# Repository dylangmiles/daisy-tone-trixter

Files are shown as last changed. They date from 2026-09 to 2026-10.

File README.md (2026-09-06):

# Tone Trixter — Daisy Seed3

A guitar pedal that makes a piezo pickup sound like a studio microphone — in real time.

**Build log & demos:** [dylangmiles.github.io/tone-trixter](https://dylangmiles.github.io/tone-trixter/)

Piezo pickups are cheap and reliable but have a characteristic harsh, nasal "quack" that EQ alone
can't fix. Tone Trixter applies an **acoustic body impulse response** to the live piezo signal using
FFT convolution, transforming it to match a condenser microphone placed in front of the same guitar.

**Status: the active development path.** The pedal plays — guitar in, DSP chain, SD-loaded IR,
backing tracks, tuner and OLED menu all running on hardware from a 9 V supply. New work happens
here; the [RP2350 build](https://github.com/dylangmiles/pico-tone-trixter) is the V1 prototype that
proved the idea and is still gigging.

---

## Why the Seed3

The V1 measurements kept arriving at the same conclusion: **the analogue front end sets the noise
floor**, not the DSP. The RP2350 build's ES8388 codec was itself a meaningful part of the noise
budget, which made that conclusion hard to test cleanly.

The Seed3's TAC5242 is 32-bit / 192 kHz with a −120 dB floor. The codec effectively stops being a
factor, and the front-end buffer becomes the *only* thing that matters for noise — which is exactly
the question this project turns on. The 480 MHz Cortex-M7 is a bonus rather than the reason.

---

## Hardware

**Processor:** Electrosmith Daisy Seed3 — STM32H750, Cortex-M7 @ 480 MHz, hardware FPU, 64 MB SDRAM
**Codec:** TI TAC5242 — 32-bit / 192 kHz, −120 dB noise floor, hardware-strapped

```
Guitar piezo → buffer daughter board (JFET follower, or OPA1642 op-amp)
  → Seed3 ADC
    → 2048-tap IR convolution (inline) → input trim → 3-band EQ
      → compressor/limiter → output level
    → backing-track mix (after the chain, deliberately)
  → Seed3 DAC → PA / headphones / interface
```

The piezo buffer lives on a swappable 5-pin daughter board, shared with the V1 build. ⚠ **The Seed3
has no input buffer of its own** and its input is line-level, so the high-impedance buffer stage is
mandatory rather than optional.

Built on cut-down perfboard with the Seed under-mounted, 9 V jack power, SH1106 OLED + rotary
encoder, two footswitches (tuner / DSP bypass), and a bit-banged microSD slot.

---

## Features

- **2048-tap IR convolution**, running inline on the M7 — no second core needed
- **DSP chain:** input trim → 3-band EQ (RBJ biquads) → compressor/limiter → output level
- **Presets** bundling all parameters plus IR selection; switching guitars re-stages the whole chain
- **SD card:** drop `tonetrix/` on a card to override presets (`presets.txt`) and add IRs
  (`ir/*.wav`) without reflashing
- **Backing tracks** streamed from the card, mixed *after* the chain so the bed never goes through
  the guitar's IR, EQ or compressor
- **YIN tuner**, full-screen, footswitch-toggled, muting, fed from the raw input
- **OLED home screen:** preset, IR, CPU load, and in / gain-reduction / out meters with a sticky
  clip indicator
- **Live USB-serial control:** every parameter adjustable while playing (`help` lists commands),
  plus timing, CPU and encoder diagnostics

⚠ **Boot is complete passthrough by design.** The pedal always starts transparent, so anything
measured at boot reflects the front end alone with no DSP on top — which matters while the analogue
path is still being characterised.

---

## Measured performance

Steady state, 48 kHz, 64-sample blocks, chain + 2048-tap IR engaged:

| Figure | Reading |
|---|---|
| Audio CPU, bypass | 1 % |
| Audio CPU, chain + IR | **16 % avg, 45 % peak** |
| Foreground loop | 6.6 ms worst, 8 ms period |
| Backing ring | 98–99 %, 0 underruns |
| Block latency | 1.33 ms |

⚠ **Two budgets, and only one is tight.** Audio has ~84 % spare — the foreground is the constrained
side, where a full OLED flush costs ~28 ms. Any optimisation belongs there, not in the audio path.

---

## Build and flash

Requires the ARM GCC toolchain, `dfu-util`, and [libDaisy](https://github.com/electro-smith/libDaisy)
+ [DaisySP](https://github.com/electro-smith/DaisySP).

```sh
make                                          # or: make LIBDAISY_DIR=/path/to/libDaisy
make program-boot                             # ONCE — installs the Daisy bootloader
make program-dfu                              # thereafter
screen /dev/tty.usbmodem* 115200              # console
```

⚠ **libDaisy must be the `seed3-updates` branch, pinned to a commit.** Seed3 support is not on
`main` — a stock libDaisy configures the wrong codec, and an unmerged branch can be force-pushed
underneath you.

⚠ **`APP_TYPE = BOOT_SRAM`.** The STM32H750 has only 128 KB of internal flash and this app does not
fit; it runs from 480 KB of internal SRAM via the Daisy bootloader, which is why `make program-boot`
is a required one-time step.

---

## Notes worth knowing before you read the code

Several things here deliberately do *not* use the obvious library call. Each has a measured reason,
documented at the point of use:

- **Our own SH1106 driver.** libDaisy's OLED transport sends one I²C transaction *per byte* — about
  77 ms per frame. Ours writes a page per transaction and sends only pages that changed.
- **Our own quadrature decode.** libDaisy's `Encoder::Increment()` needs one exact sample pattern
  that a detented PEC11R rarely produces; it works only within a narrow band of turn speeds.
- **Bit-banged SD over SPI.** The Daisy's SDMMC `CMD` pin is wired to ground on this layout, and the
  breakout's pin order matches no hardware SPI instance.
- **`-u _printf_float` in the Makefile.** libDaisy links `--specs=nano.specs`, and newlib-nano omits
  floating-point conversion from `printf` — every `%f` silently prints nothing without it.

`CLAUDE.md` carries the full engineering detail, including the hardware gotchas that cost bench time.

---

## Relationship to the RP2350 build

The two pedals share the analogue front end, the DSP chain design, the IR capture method, and **one
physical SD card** — the card layout lives once, in the
[Pico repo](https://github.com/dylangmiles/pico-tone-trixter), and both firmwares read it.

Driver sources that could reasonably be shared are kept byte-identical between the builds behind
small platform shims, so a protocol or layout fix on either platform applies to both.

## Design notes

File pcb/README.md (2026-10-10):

# Tone Trixter PCB — rev A

KiCad 10 project. **The schematic is GENERATED**: edit `tools/gen_schematic.py`, run it, never hand-edit
`tone_trixter.kicad_sch` (the next run overwrites it). Design intent and every value's reason are in
`private/docs/daisy_pcb_brief_2026-09-16.md`; pin numbers come from `../board.h`.

```
tools/gen_schematic.py          # the source of truth for the schematic
tools/kisch.py, tools/kisym.py  # tiny writer + KiCad-library symbol extractor
tone_trixter.kicad_sch          # generated
tone_trixter.kicad_pro          # project (created once)
TT.kicad_sym, sym-lib-table     # the Daisy Seed3 symbol, built from the pinout CSV
tone_trixter_schematic.pdf      # review print
```

Check: `kicad-cli sch erc tone_trixter.kicad_sch` (only "symbol differs from library" notices expected —
the op-amp and SD symbols are flattened copies) and `kicad-cli sch export netlist`. `gen_schematic.py`
also runs a wire-through-pin check and prints `CHECK:` lines if any wire crosses a pin it should not.

## Layout (started 2026-10-09)

The enclosure mock-up revised the brief's board envelope. **Current geometry** (see
`tools/gen_mockup_svg.py` + `tools/gen_side_elevation_svg.py`, rendered in `mockup/`):

- 1590XX **landscape** (internal top-face plane 138 × 114, **2.33 mm walls**, internal cavity **33 mm**
  tall, Ø7 corner bosses). All measured off the box 2026-10-10.
- **Full-width board ~132 × 57 mm**, hugging the **back wall**, rear corners notched **10 × 10** for the
  bosses (Ø7 post → 3 mm play). Mounted high under the top face (**gap 8.24 mm**, set by the OLED glass
  flush + encoder body clearing); **Seed hangs ~16.5 below**; OLED + encoder reach up (screen centred on
  the board, toward the rear); footswitches panel-mounted up front at 90 mm centres.
- **TRS + DC jacks bottom-mounted** (barrel 12.4 below the board → axis **~33 % up the wall, lower
  third**, z ≈ 10.8), legs up through the PCB, isolated plastic bushings. **USB = Seed's own port** on a
  flexible extender. **Two high-Z inputs drilled in v1** — IN A (AIN1) + IN B (AIN2), both K3599 TRS;
  the XLR mic reserve is dropped (a v2 board).
- ✅ All Z-stack heights (OLED/encoder/Seed/jack/cavity) **measured** 2026-10-10; see the side-elevation.

**The outline is GENERATED** — `tools/gen_board.py` (run with KiCad's bundled python; has `pcbnew`):

```
/Applications/KiCad/KiCad.app/Contents/Frameworks/Python.framework/Versions/Current/bin/python3 \
    tools/gen_board.py          # writes tone_trixter.kicad_pcb: Edge.Cuts outline + M3 holes only
```

Then in KiCad: open `tone_trixter.kicad_pcb`, **Tools → Update PCB from Schematic (F8)** to pull in
the 102 footprints (the schematic has them all assigned), place per the mock-up, route, DRC, 3D-check
against the box height, Gerbers. One plane (bottom pour), star at power entry; no copper within 1 mm
of the edge; mounting holes become plane-bonded once the enclosure bond is finalised.

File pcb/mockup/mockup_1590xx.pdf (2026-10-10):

## 1590XX mock-up (landscape) -- PRINT AT 100%, verify the 100 mm ruler

Box: ext ~145x121x39 (catalog), wall 2.33, top-face plane 138x114, cavity 33 tall, O7 corner bosses.
Full-width notched board; jacks board-mounted. IN A + IN B = two high-Z TRS inputs (both drilled v1).

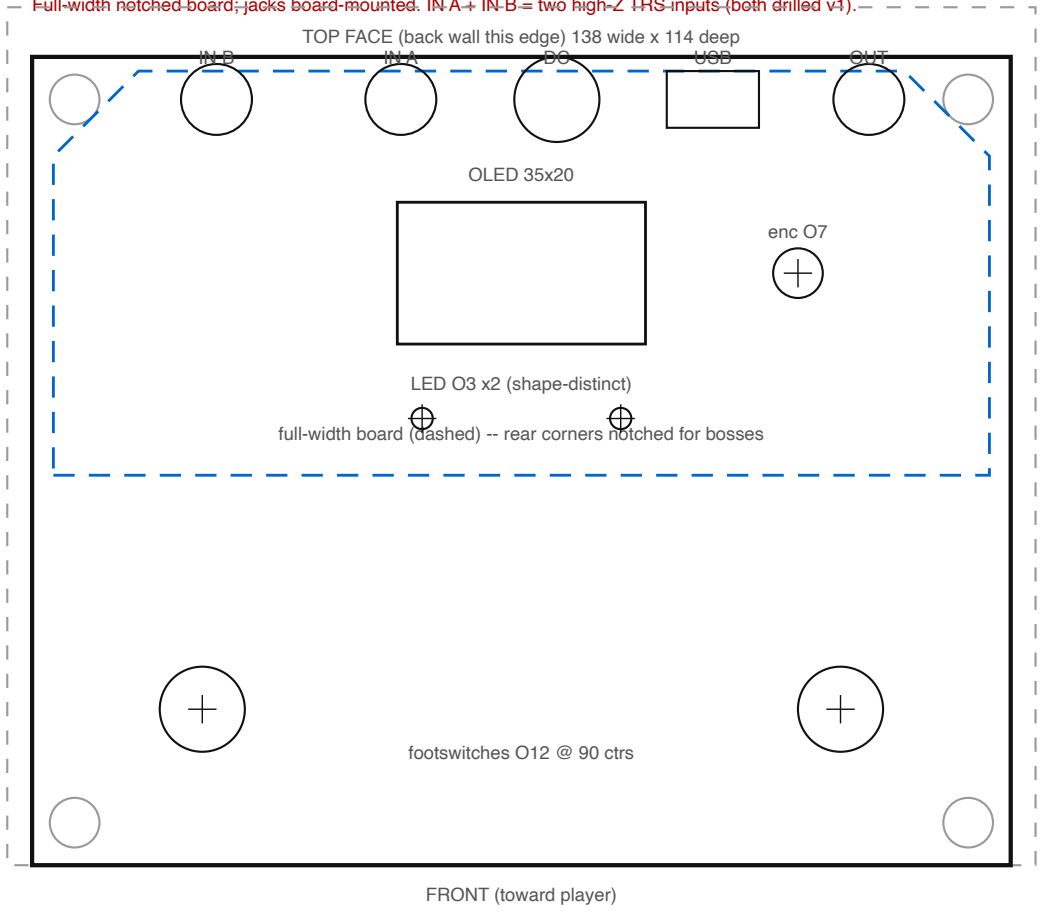
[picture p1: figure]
FRONT (toward player); footswitches O12 @ 90 ctrs; LED O3 x2 (shape-distinct); OLED 35x20; enc O7; USB; OUT

TOP FACE (back wall this edge) 138 wide x 114 deep

full-width board (dashed) -- rear corners notched for bosses

REAR WALL drilling strip (138 wide x 33 tall, base at BOTTOM) -- same X as above; hole at its axis height

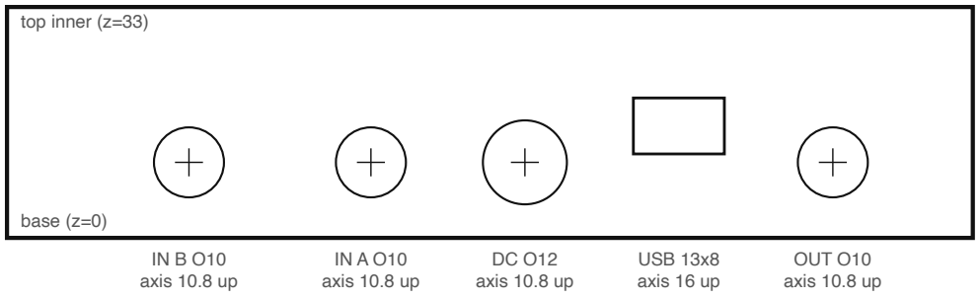
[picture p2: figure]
base (z=0); top inner (z=33); IN B O10 axis 10.8 up; IN A O10 axis 10.8 up; DC O12 axis 10.8 up; USB 13x8 axis 16 up; OUT O10 axis 10.8 up

this bar MUST measure 100.0 mm -- if not, fix the print scale

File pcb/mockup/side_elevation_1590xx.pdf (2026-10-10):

## 1590XX SIDE ELEVATION (height study, projected) -- PRINT AT 100%

ALL heights MEASURED off the prototype + box 2026-10-10 (recalibrated caliper). Front=left, back wall=right.
Cavity 33 mm (35.30 box - 2.3 top), walls 2.33 mm. Gap 8.24 (OLED glass flush, encoder clears). Jack axis 12.4 below the board.

top face

base plate

FRONT (toward player) --- BACK WALL (jacks)

Seed3 + sockets ~16.5
(hangs below the PCB)
| OLED glass (flush w/ top inner)
PCB | | standoff 8.24

encoder shaft (+16.61 over top)

jack z=10.77 (bottom-mt)

0 base

7 Seed btm

11 jack axis

25 board/jack

33 top inner

Jacks BOTTOM-MOUNTED (barrel below the board) -> axis z=9.8 = ~33% up the 33 mm wall (lower third) -- barrel drop 12.4 + the 8.2 gap the gap the controls force. Check the plug + base-plate battery box do not crowd down there on the casting.
Seed hangs to ~6.7 mm over the base (16.5 stack). TRS/DC bottom-mount, legs up; USB = Seed's own port.

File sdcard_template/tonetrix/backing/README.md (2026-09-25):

# Backing tracks

Drum beds for playing along. Select with the OLED `BK:` menu row, or over UART:

    bk                 list (* = playing)
    bk 0 | bk blues92  play by index or name
    bk off             stop
    bk level 0.8       level, independent of out.level
    bk stat            ring fill, underruns, worst service time

Loops are **pure data** — drop a new WAV in this folder and `bk scan` picks it up.
No reflash. Any rate, 8/16/24/32-bit or float, mono or stereo; it is resampled to the
engine rate on the fly. These are 48 kHz mono 16-bit, peak −6 dBFS to leave headroom
for the guitar summed on top.

## Beat 1 is marked with a bell

Every bar's **1** carries a short inharmonic bell (~2.1 kHz, ~55 ms). It is
deliberately not a kit voice: a few dB of accent is easy to lose once a guitar is on
top, so the downbeat differs in *timbre*, not level. Inharmonic rather than a pure
tone, so it reads as percussion instead of a note that fights whatever key you are in.

Turn it down or off when you no longer need it — see *Regenerating* below.

## The loops

⚠ **Song suggestions are starting points, not matches.** These are generic grooves in
the right style — never reproductions. The tempos were chosen from where each style
usually sits, **not measured against any recording**, so expect to want a nudge.

| File | bpm | Feel | Try it with |
|---|---|---|---|
| `delta72` |  72 | Sparse Delta shuffle, as `delta81`, slower | **"Come Back Baby" — Lightnin' Hopkins** *(requested)* |
| `stomp71` |  71 | **Foot-stomp + handclap**: kick on all four, claps on 2 and 4, nothing else | **"Am I Wrong" — Keb' Mo'** *(requested 2026-09-18)* |
| `blues71` |  71 | Same country blues shuffle as `blues92`, slower and heavier | slow shuffle |
| `delta81` |  81 | **Sparse Delta shuffle**: kick 1 & 3, rim 2 & 4, whisper of hat | **"Walking Blues" — Muddy Waters**, **"Sweet Home Chicago"** *(requested)* |
| `ballad62`  |  62 | **Slow 4/4 ballad, as sparse as it gets**: kick on 1, rim on 3, brushed 2 & 4 barely there | **"Desperado" — Eagles** *(requested)* |
| `folksh92`  |  92 | Slow brushed **12/8 shuffle** (in four), swirl on the "and" | **"Angel from Montgomery" — Prine / Raitt** *(requested)* |
| `folksh96`  |  96 | Gentle 12/8 lilt, brushed | **"Wonderful Tonight" — Eric Clapton** *(requested)* |
| `ssoul78` |  78 | **Slow soul pocket**: kick 1 + pickup into 3, cross-stick 2 & 4, light swung hat | **"Ain't No Sunshine" — Bill Withers** *(requested)* |
| `waltz100`  | 100 | **3/4 waltz** (in three), bass on 1, brushed 2 & 3, light hat | **"Scarborough Fair" — Simon & Garfunkel** *(requested)* |
| `rise76` |  76 | **True 6/8**, felt in TWO — bass on 1 & 4, light hat over the six eighths | **"House of the Rising Sun" — The Animals** *(requested)* |
| `folksh76`  |  76 | Slow brushed shuffle, **12/8 (counted in four)**, swirl on the shuffle "and" | slow 12/8 blues/ballads |
| `blues81` |  81 | Same country blues shuffle as `blues92`, a little slower | slow Delta blues, slide |
| `folkd92` |  92 | **Driving acoustic folk-rock**: kick on every beat, snare 2 & 4, 8th hat | **"Can't Find My Way Home" — Blind Faith** *(requested)* |
| `folkd140`  | 140 | Same driving folk bed, up-tempo country strum | **"Wagon Wheel" — Old Crow / Darius Rucker** *(requested; 150 eased to 140)* |
| `blues92` |  92 | Country blues shuffle, 12/8, ride-style hat, ghost notes | acoustic country blues, slide |
| `delta92` |  92 | Sparse Delta shuffle, as `delta81` | **"Cross Road Blues"** acoustic *(requested)* |
| `delta100`  | 100 | Sparse Delta shuffle, as `delta81` | (spare) |
| `delta101`  | 101 | Sparse Delta shuffle, as `delta81` | **"Cross Road Blues"** *(requested)* |
| `delta110`  | 110 | Sparse Delta shuffle, as `delta81`, brisker | **"Cross Road Blues"** faster *(requested)* |
| `blues100`  | 100 | Same country blues shuffle as `blues92`, a touch brisker | **"I Can't Be Satisfied" — Muddy Waters** *(requested)* |
| `folk104` | 104 | Light two-step with brushes, cross-stick | country folk, fingerstyle |
| `rock120` | 120 | Straight 8ths, backbeat, open-hat lift into the turnaround | general rock |
| `folkr128`  | 128 | Gentle country-folk-rock, soft brushed backbeat, sparse kick | **"Old Man" — Neil Young**, **"Father and Son" — Cat Stevens** *(requested)* |
| `rkbly138`  | 138 | Rockabilly, handclaps on the backbeat, more bounce | slower take on the below |
| `soul140` | 140 | Soul-pop with a little pocket | slower take on the below |
| `soull150`  | 150 | **Soul-pop, simplified**: kick 1 & 3, snare 2 & 4, straight hat, no ghosts, no fill | **"Brown Eyed Girl" — Van Morrison** *(requested; the full kit was busy under strummed acoustic)* |
| `soul150` | 150 | Bright uptempo soul-pop, full kit, driving 8ths | the busier take on the above |
| `rkbly145`  | 145 | Rockabilly bounce, handclaps doubling the backbeat | **"Crazy Little Thing Called Love" — Queen** *(requested; 156 was too quick)* |
| `rkbly156`  | 156 | Rockabilly bounce, handclaps doubling the backbeat | brisker take on the above |

All are **4 bars**, seamless, and start exactly on beat 1.

⚠ `blues71` / `blues81` / `blues92` / `blues100` are the **same groove at four tempos** — identical pattern,
identical swing. Rendered from one style, so a change to the feel applies to all three:

    python3 tools/gen_backing_loops.py country_blues --bpm 71     # from daisy/

## Regenerating

Everything here is synthesised by `daisy/tools/gen_backing_loops.py` (moved from `pico/tools/`
on 2026-09-18 — the Pico copy is frozen with that build) —
no samples, nothing licensed. Grooves are data (step/velocity lists in `STYLES`), so
changing a pattern is an edit, not new code.

    python3 tools/gen_backing_loops.py                     # all styles, defaults
    python3 tools/gen_backing_loops.py rock --bpm 132      # retune one
    python3 tools/gen_backing_loops.py soul_pop --bpm 140 --swing 0.06
    python3 tools/gen_backing_loops.py rock --ping 0       # no beat-1 bell

Knobs: `--bpm`, `--swing` (0 = straight, ~0.33 = full triplet), `--accent` (beat-1
level), `--ping` (beat-1 bell level, 0 = off). The render line prints all four, so a
re-render says what it did.

⚠ **The tempo is part of the filename.** Re-rendering at a new tempo writes a *new*
file rather than replacing the old one — delete the stale one or you will have both
in the picker.

## Loading the card

    cp .../sdcard_template/tonetrix/backing/*.wav /Volumes/<CARD>/tonetrix/backing/
    dot_clean -m /Volumes/<CARD>/tonetrix

`dot_clean` strips the `._name.wav` sidecars macOS writes on FAT volumes. The firmware
ignores them, but they clutter the card.

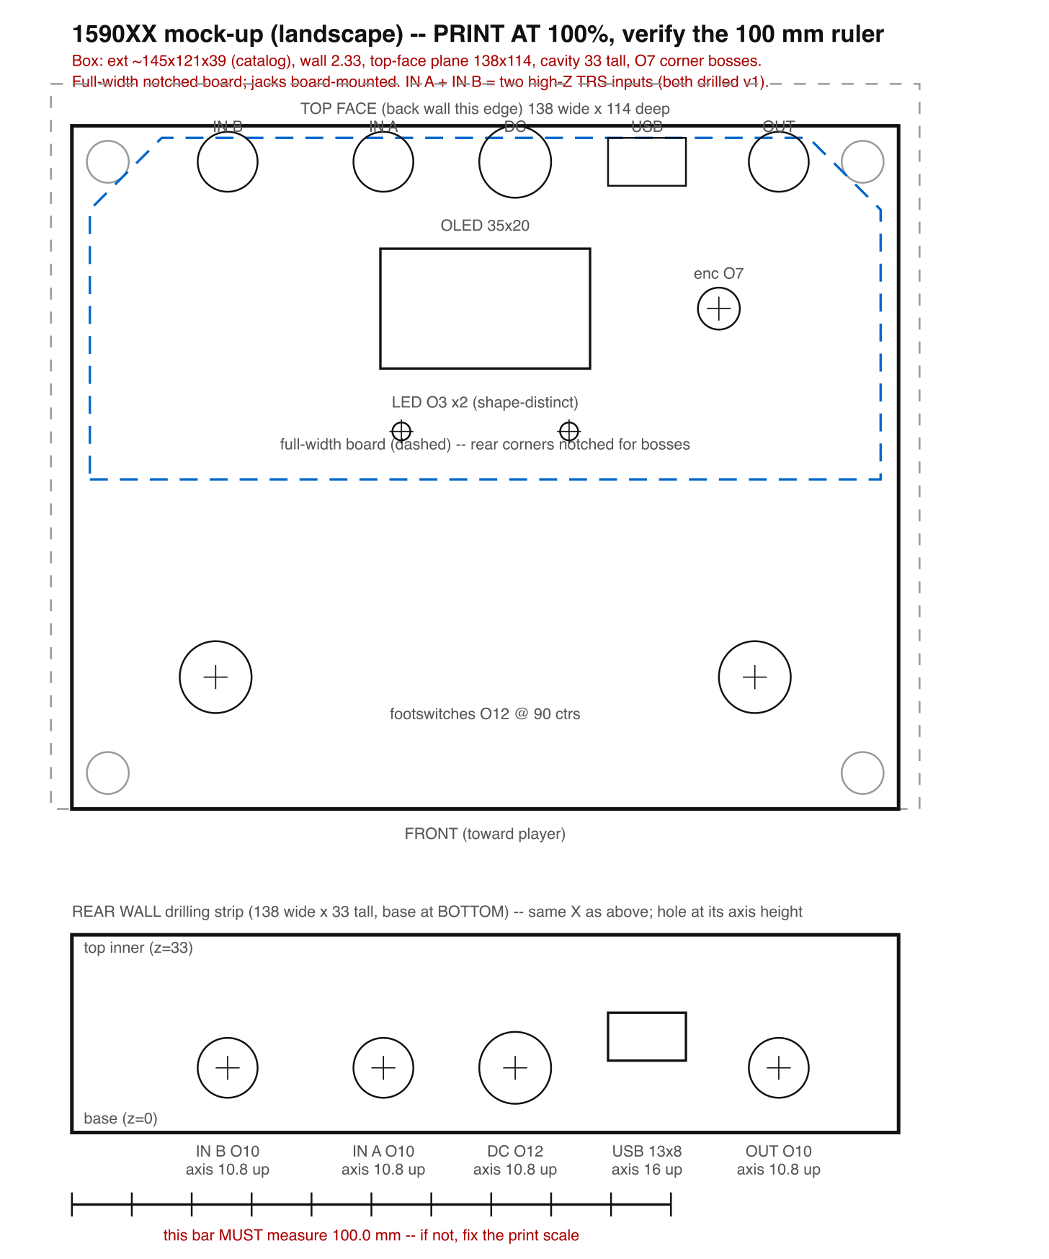
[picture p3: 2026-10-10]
pcb/mockup/mockup_preview.png

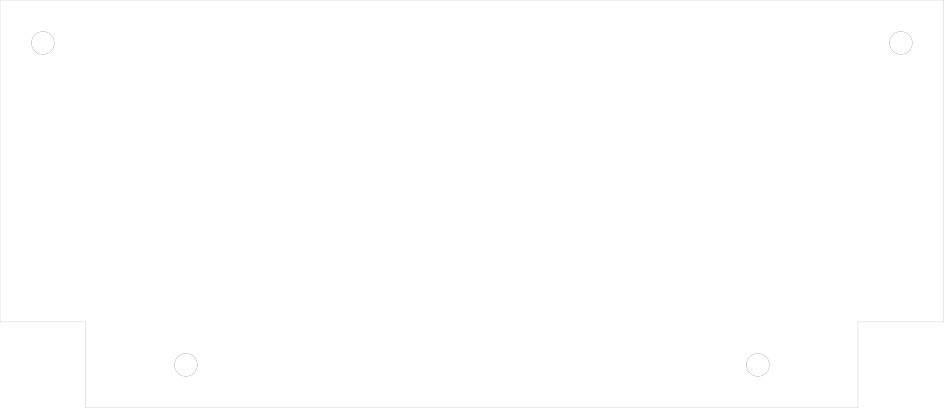
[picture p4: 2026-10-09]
pcb/mockup/board_outline_preview.png

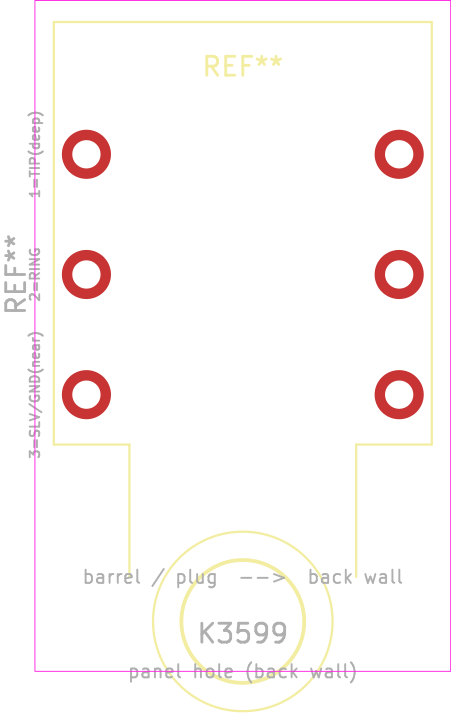
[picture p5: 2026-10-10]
pcb/mockup/k3599_footprint.png

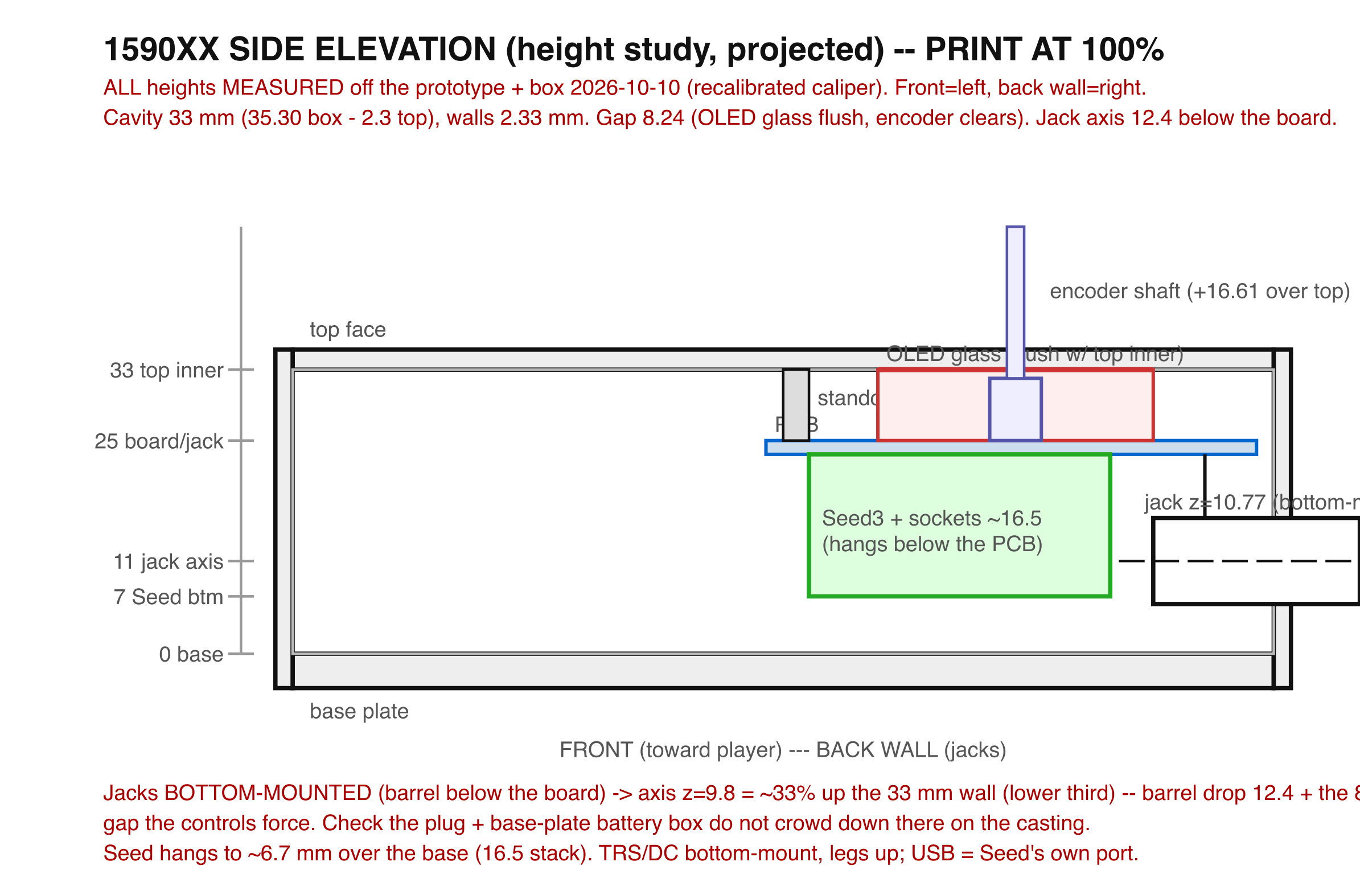
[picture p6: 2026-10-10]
pcb/mockup/side_elevation_preview.png

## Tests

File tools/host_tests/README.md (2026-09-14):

# Host tests

Engine logic that is cheap to prove on the Mac and expensive to debug underfoot.

```
cd tools/host_tests
c++ -std=c++14 -O1 -I../.. -I. looper_test.cpp ../../audio/looper.cpp -o looper_test && ./looper_test
```

`dev/sdram.h` stubs `DSY_SDRAM_BSS` so `looper.cpp` compiles unchanged. Covers: first pass → play,
overdub auto-commit after one loop, undo stack, an overdub cut short (extent tracking), stop/play
from the top, tempo lock (bpm + bars), bar snap (bpm only), the 60 s cap, and the free-loop bpm guess.

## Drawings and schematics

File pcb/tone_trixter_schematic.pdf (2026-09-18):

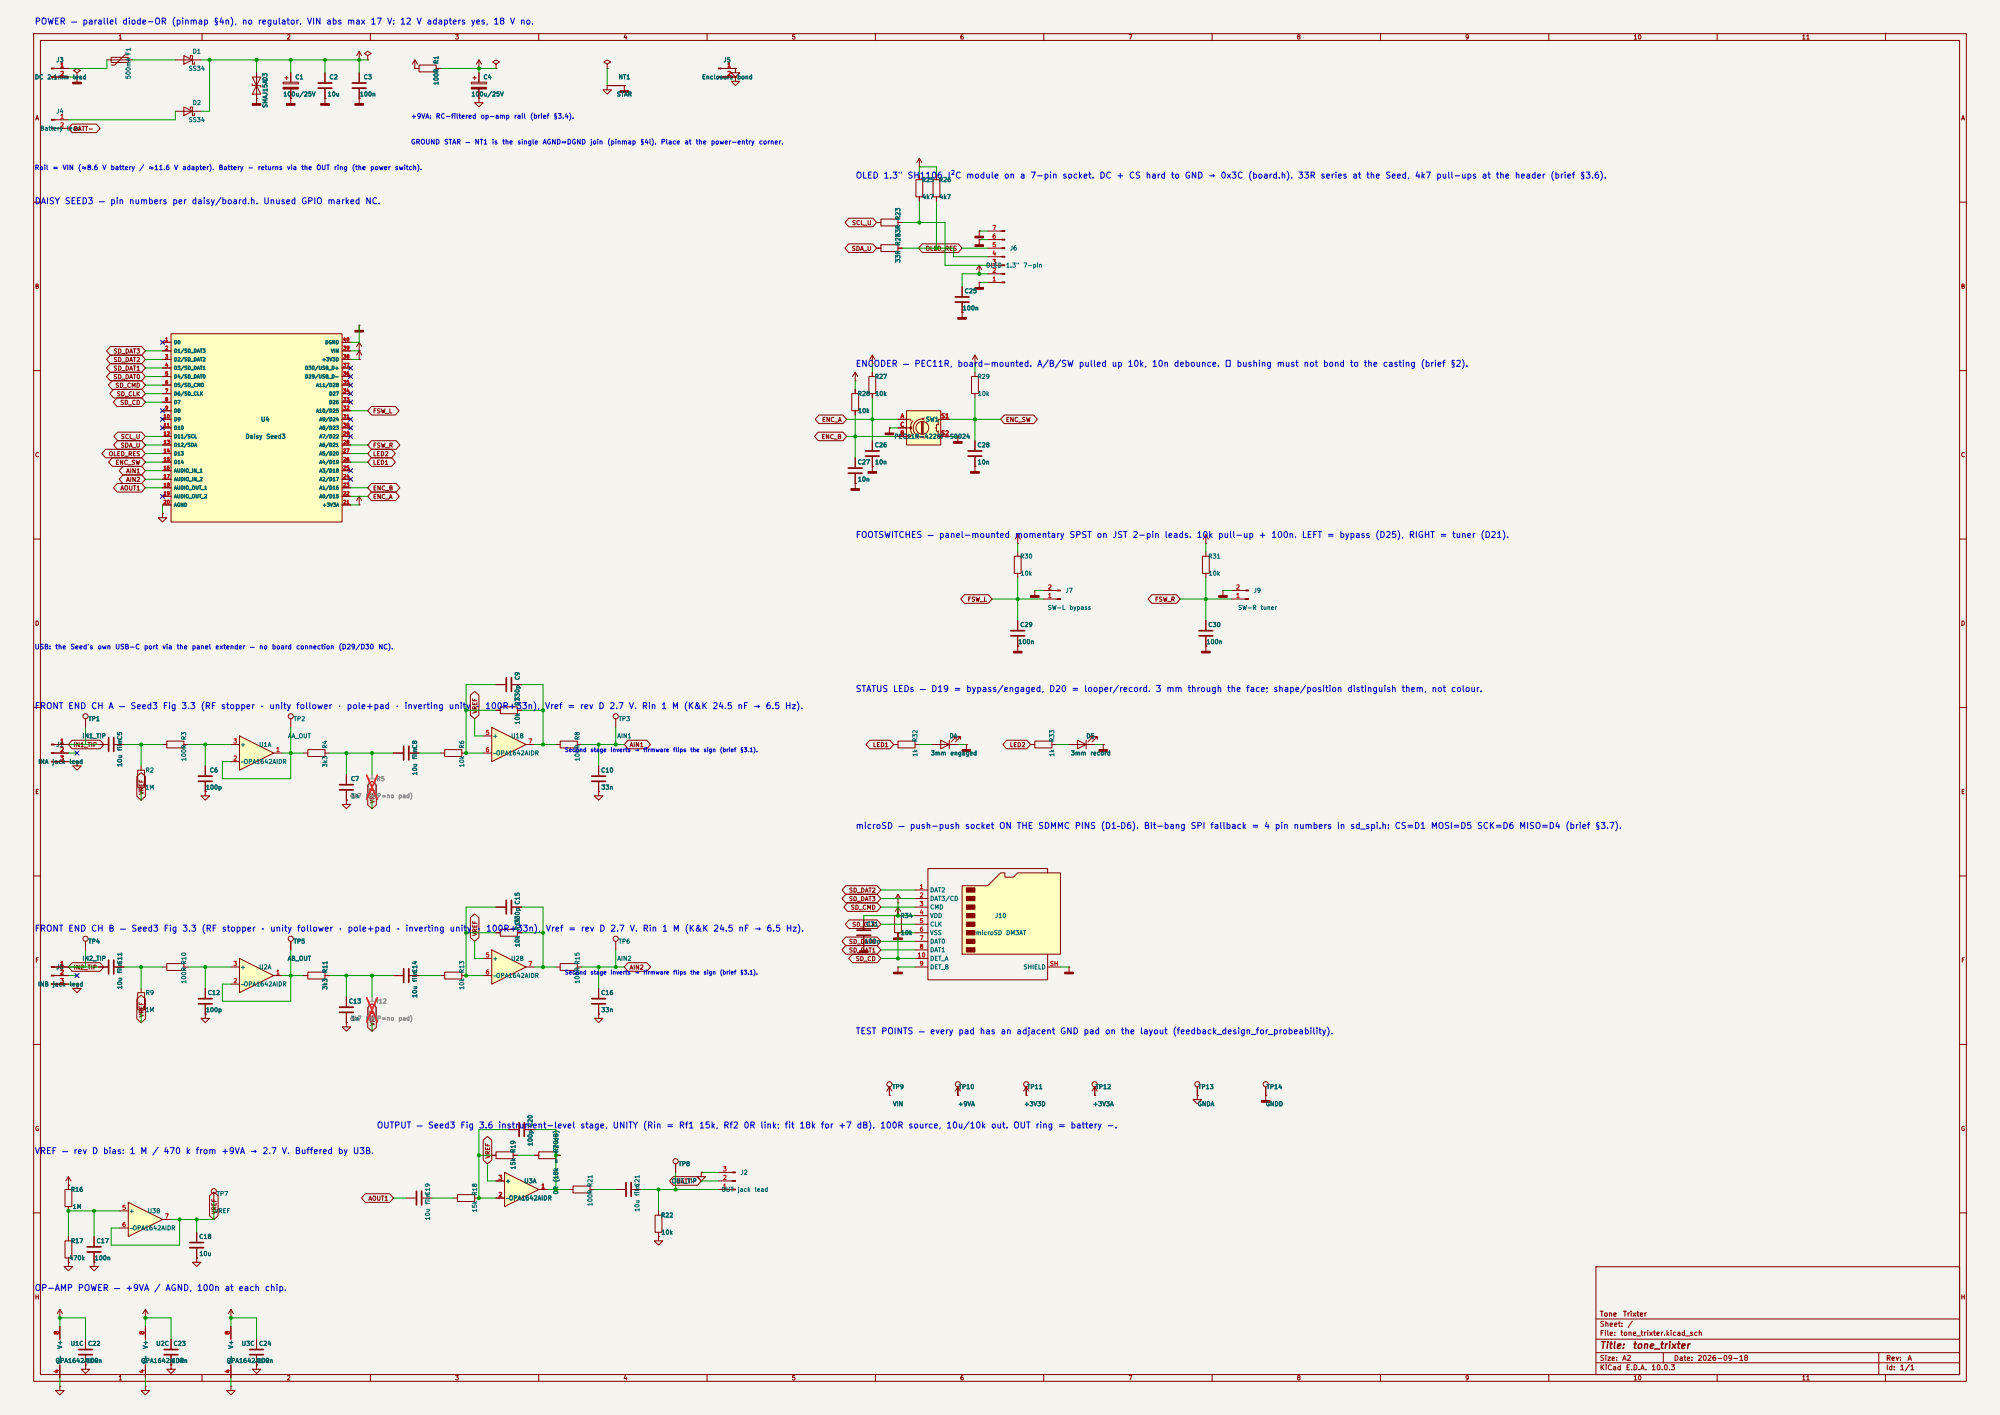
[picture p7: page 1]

POWER — parallel diode-OR (pinmap §4n), no regulator. VIN abs max 17 V: 12 V adapters yes, 18 V no.
100u/25V D3 SMAJ15A U4 Daisy Seed3

+9VA: RC-filtered op-amp rail (brief §3.4). GROUND STAR — NT1 is the single AGND↔DGND join (pinmap §4l). Place at the power-entry corner.

DAISY SEED3 — pin numbers per daisy/board.h. Unused GPIO marked NC. Rail = VIN (≈8.6 V battery / ≈11.6 V adapter). Battery − returns via the OUT ring (the power switch).

OLED 1.3" SH1106 I²C module on a 7-pin socket. DC + CS hard to GND → 0x3C (board.h). 33R series at the Seed, 4k7 pull-ups at the header (brief §3.6).

ENCODER — PEC11R, board-mounted. A/B/SW pulled up 10k, 10n debounce. ⚠ bushing must not bond to the casting (brief §2).

FOOTSWITCHES — panel-mounted momentary SPST on JST 2-pin leads. 10k pull-up + 100n. LEFT = bypass (D25), RIGHT = tuner (D21).

STATUS LEDs — D19 = bypass/engaged, D20 = looper/record. 3 mm through the face; shape/position distinguish them, not colour.

microSD — push-push socket ON THE SDMMC PINS (D1–D6). Bit-bang SPI fallback = 4 pin numbers in sd_spi.h: CS=D1 MOSI=D5 SCK=D6 MISO=D4 (brief §3.7).

TEST POINTS — every pad has an adjacent GND pad on the layout (feedback_design_for_probeability). C11 10u film

OUTPUT — Seed3 Fig 3.6 instrument-level stage, UNITY (Rin = Rf1 15k, Rf2 0R link; fit 18k for +7 dB). 100R source, 10u/10k out. OUT ring = battery −.

VREF — rev D bias: 1 M / 470 k from +9VA → 2.7 V. Buffered by U3B.

OP-AMP POWER — +9VA / AGND, 100n at each chip.

Size: A2 | Rev: A
KiCad E.D.A. 10.0.3 | Id: 1/1

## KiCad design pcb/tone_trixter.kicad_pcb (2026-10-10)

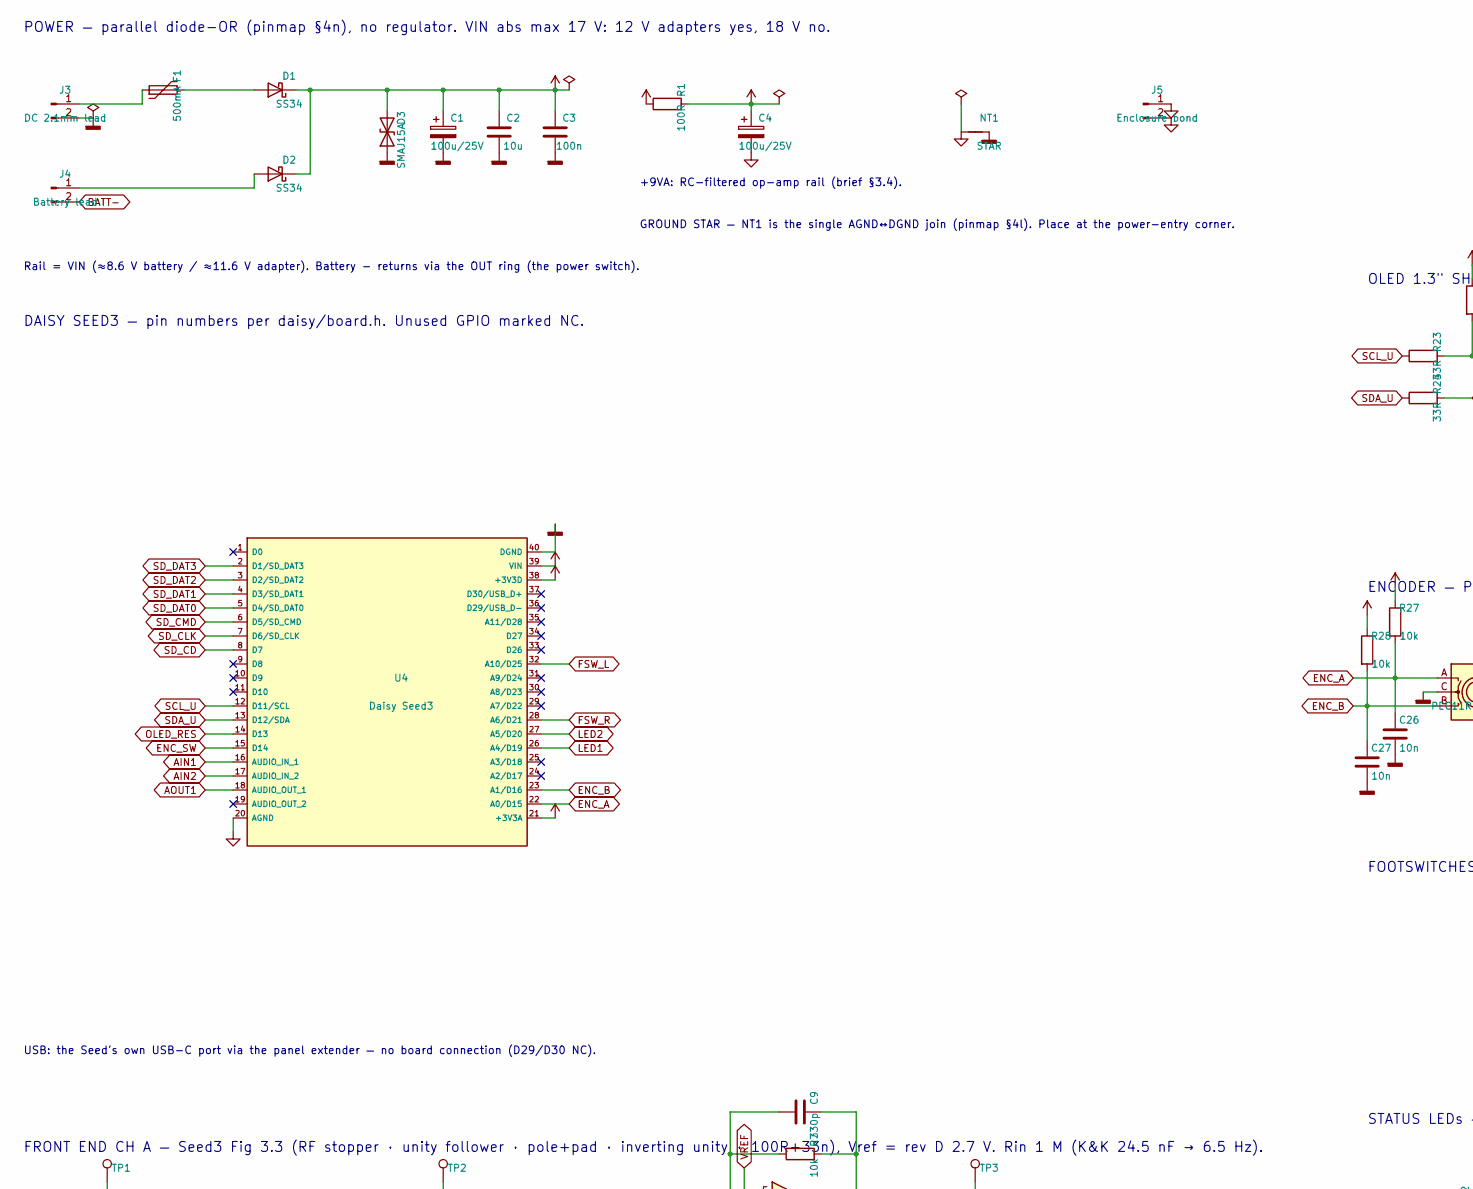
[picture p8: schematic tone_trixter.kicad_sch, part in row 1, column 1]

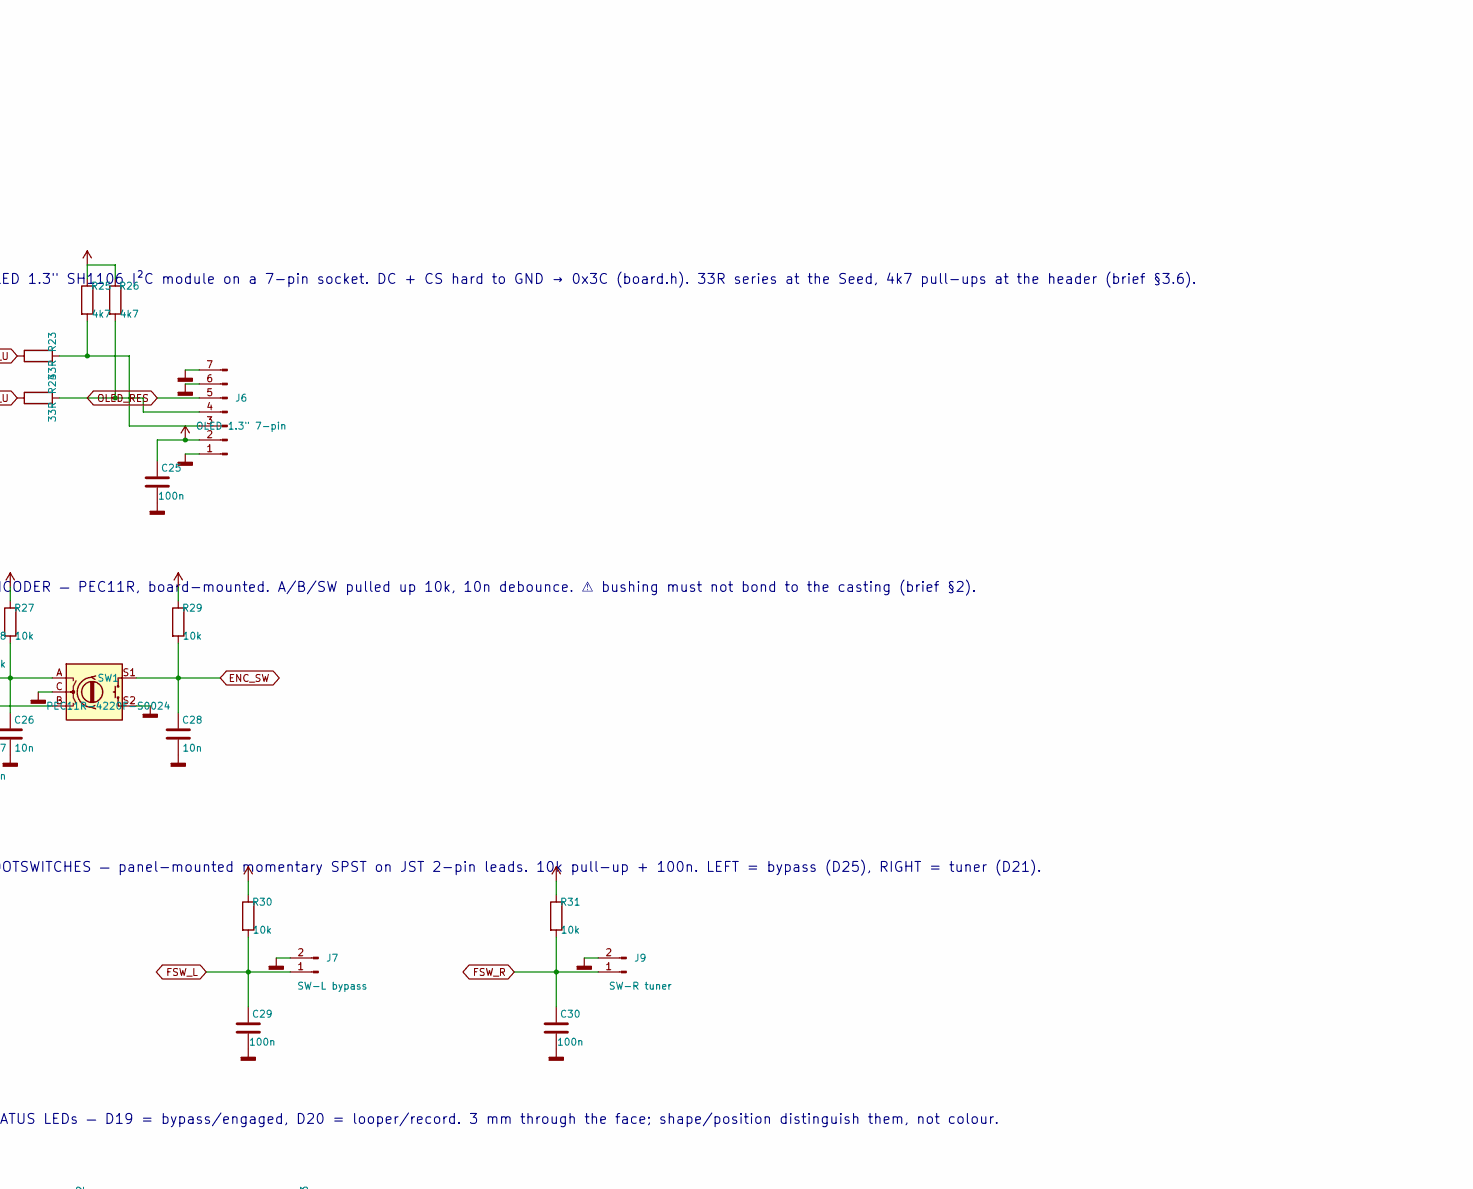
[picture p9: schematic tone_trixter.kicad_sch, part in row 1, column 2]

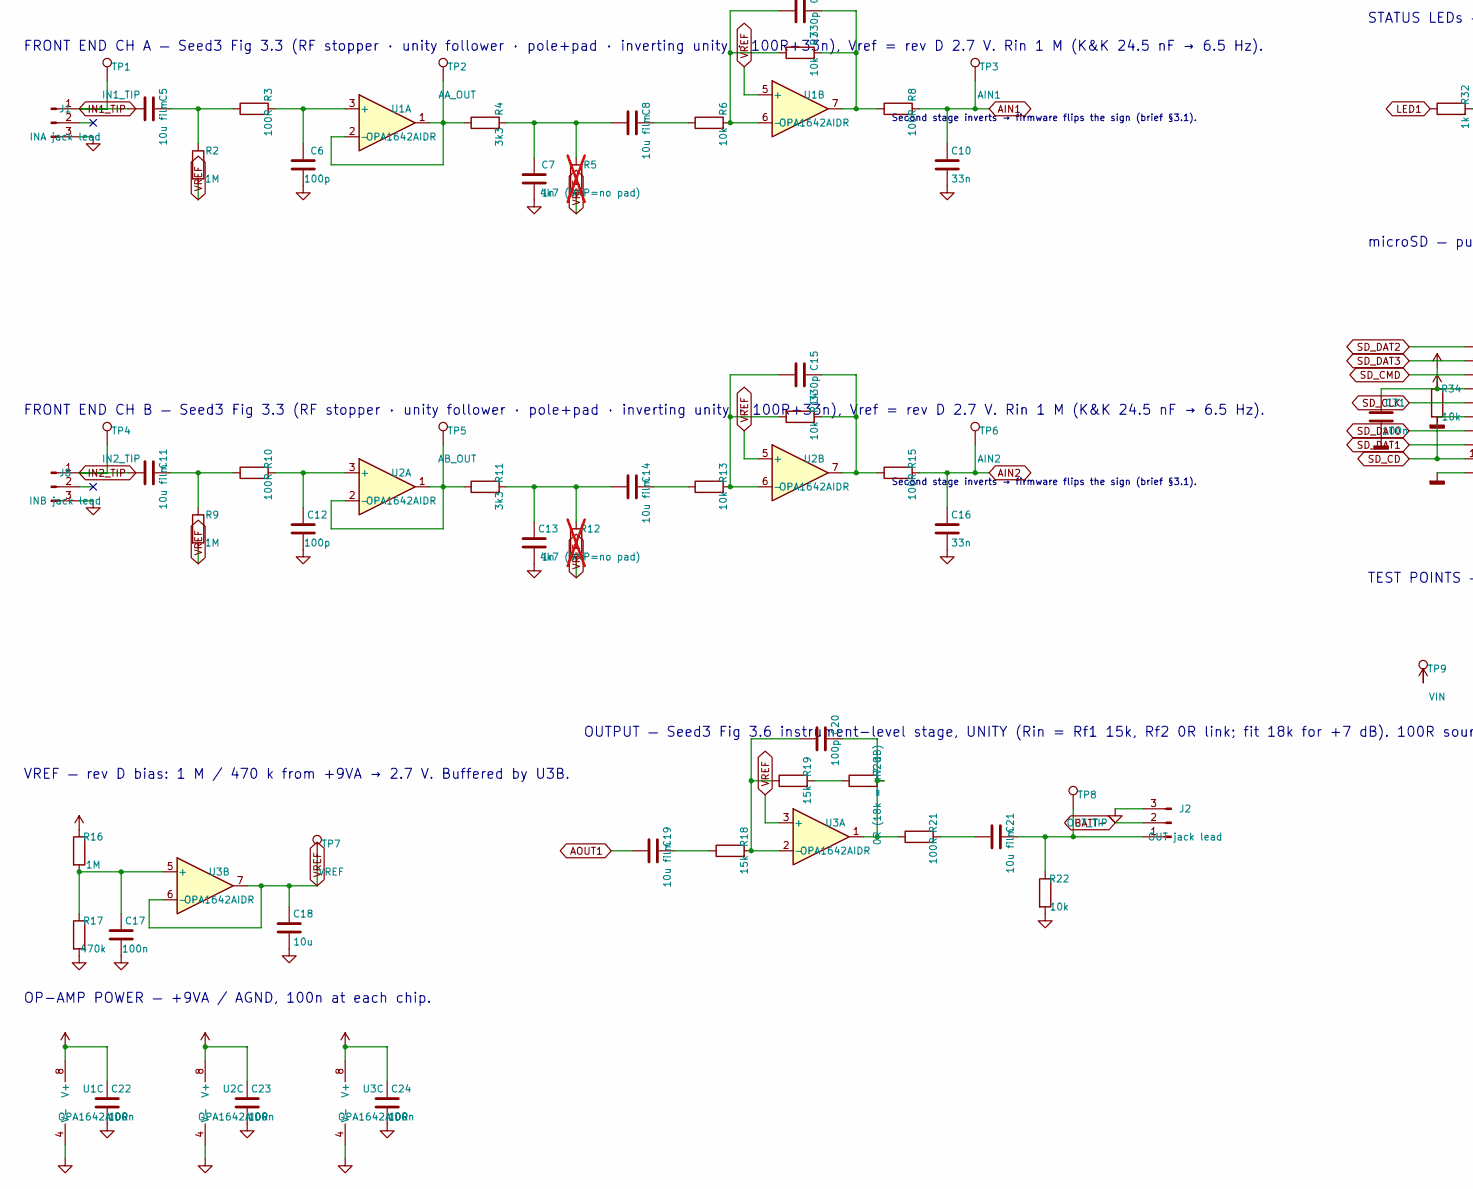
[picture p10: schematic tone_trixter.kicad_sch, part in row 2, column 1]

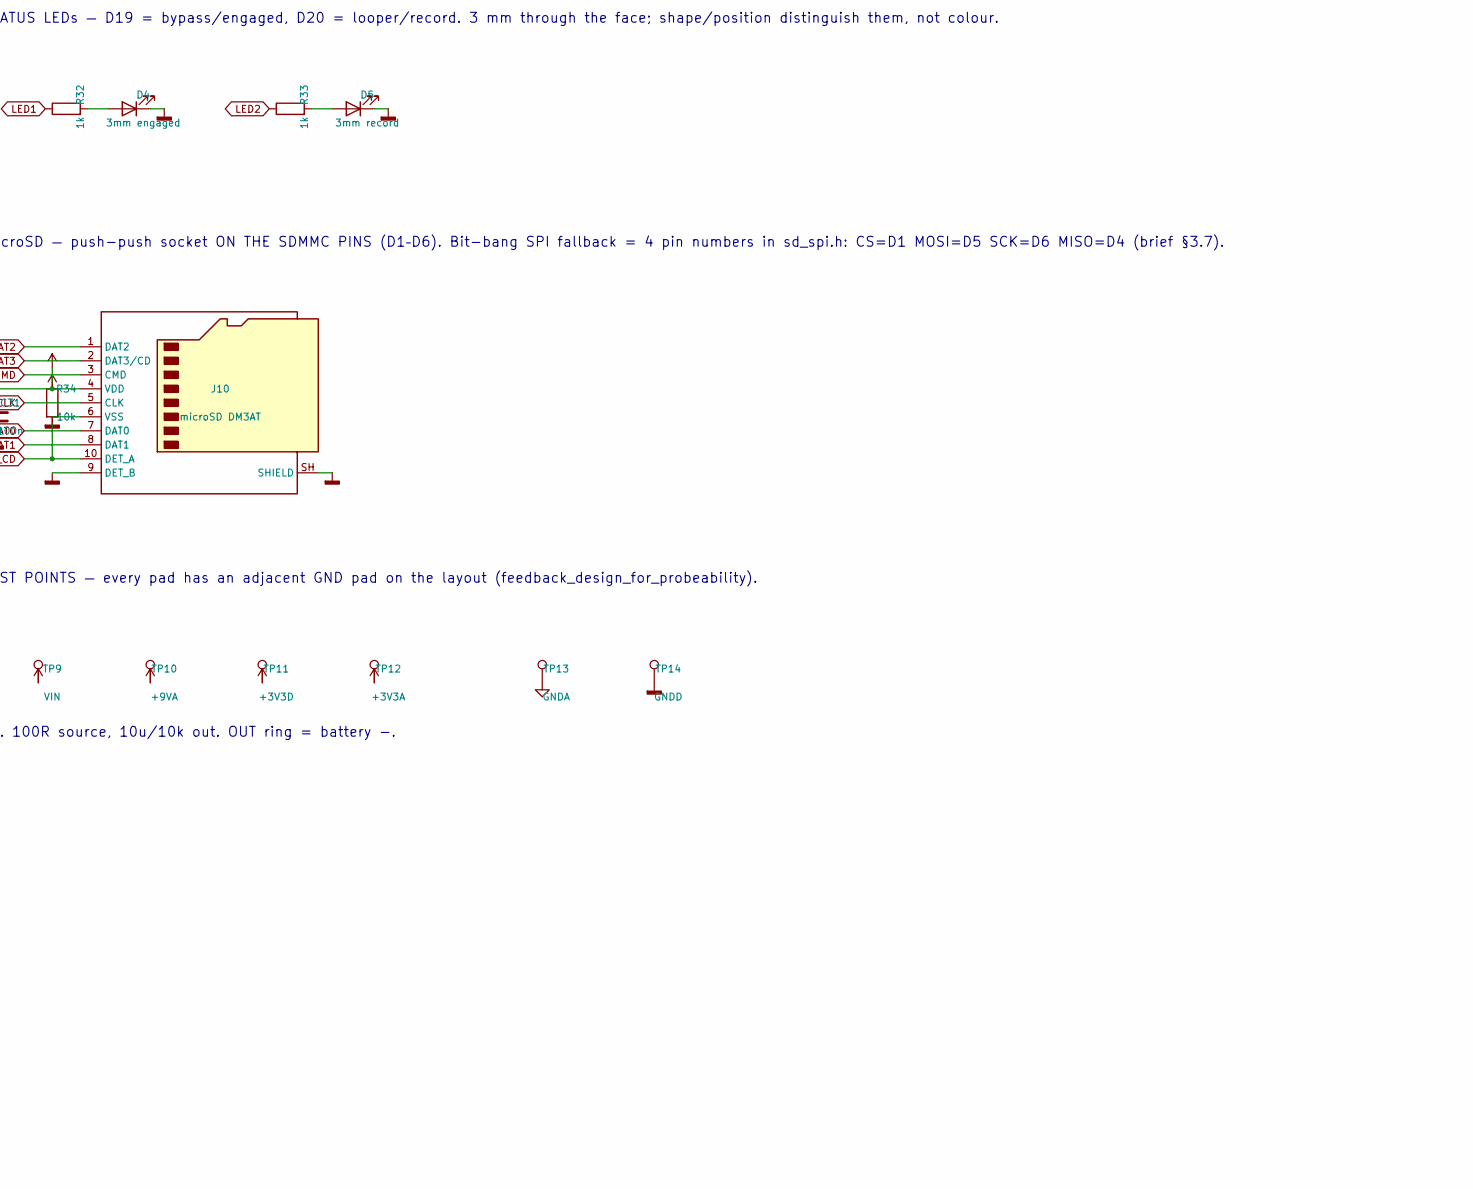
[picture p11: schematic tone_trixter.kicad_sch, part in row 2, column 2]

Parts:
C1, C4: 100u/25V; CP_Radial_D6.3mm_P2.50mm
C2, C18: 10u; C_0805_2012Metric
C3, C17, C22, C23, C24, C25, C29, C30, C31: 100n; C_0805_2012Metric
C5, C8, C11, C14, C19, C21: 10u film; C_Rect_L7.2mm_W7.2mm_P5.00mm_FKS2_FKP2_MKS2_MKP2
C6, C12, C20: 100p; C_0805_2012Metric
C7, C13: 1n; C_0805_2012Metric
C9, C15: 330p; C_0805_2012Metric
C10, C16: 33n; C_0805_2012Metric
C26, C27, C28: 10n; C_0805_2012Metric
D1, D2: SS34; D_SMA; LCSC C8678
D3: SMAJ15A; D_SMA; LCSC C129213
D4: 3mm engaged; LED_D3.0mm
D5: 3mm record; LED_D3.0mm
F1: 500mA; Fuse_1812_4532Metric; LCSC C883116
J1: INA jack lead; K3599_TRS_6leg
J2: OUT jack lead; K3599_TRS_6leg
J3: DC 2.1mm lead; JST_XH_B2B-XH-A_1x02_P2.50mm_Vertical
J4: Battery lead; JST_XH_B2B-XH-A_1x02_P2.50mm_Vertical
J5: Enclosure bond; JST_XH_B2B-XH-A_1x02_P2.50mm_Vertical
J6: OLED 1.3" 7-pin; PinSocket_1x07_P2.54mm_Vertical
J7: SW-L bypass; JST_XH_B2B-XH-A_1x02_P2.50mm_Vertical
J8: INB jack lead; JST_XH_B3B-XH-A_1x03_P2.50mm_Vertical
J9: SW-R tuner; JST_XH_B2B-XH-A_1x02_P2.50mm_Vertical
J10: microSD DM3AT; microSD_HC_Hirose_DM3AT-SF-PEJM5; LCSC C114218
NT1: STAR; NetTie-2_SMD_Pad0.5mm
R1, R3, R8, R10, R15, R21: 100R; R_0805_2012Metric
R2, R9, R16: 1M; R_0805_2012Metric
R4, R11: 3k3; R_0805_2012Metric
R5, R12: 4k7 (DNP=no pad); R_0805_2012Metric; not fitted
R6, R7, R13, R14, R22, R27, R28, R29, R30, R31, R34: 10k; R_0805_2012Metric
R17: 470k; R_0805_2012Metric
R18, R19: 15k; R_0805_2012Metric
R20: 0R (18k = +7 dB); R_0805_2012Metric
R23, R24: 33R; R_0805_2012Metric
R25, R26: 4k7; R_0805_2012Metric
R32, R33: 1k; R_0805_2012Metric
SW1: PEC11R-4220F-S0024; RotaryEncoder_Alps_EC11E-Switch_Vertical_H20mm_CircularMoun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
TP1: IN1_TIP; TestPoint_Pad_D1.5mm
TP2: AA_OUT; TestPoint_Pad_D1.5mm
TP3: AIN1; TestPoint_Pad_D1.5mm
TP4: IN2_TIP; TestPoint_Pad_D1.5mm
TP5: AB_OUT; TestPoint_Pad_D1.5mm
TP6: AIN2; TestPoint_Pad_D1.5mm
TP7: VREF; TestPoint_Pad_D1.5mm
TP8: OUT_TIP; TestPoint_Pad_D1.5mm
TP9: VIN; TestPoint_Pad_D1.5mm
TP10: +9VA; TestPoint_Pad_D1.5mm
TP11: +3V3D; TestPoint_Pad_D1.5mm
TP12: +3V3A; TestPoint_Pad_D1.5mm
TP13: GNDA; TestPoint_Pad_D1.5mm
TP14: GNDD; TestPoint_Pad_D1.5mm
U1, U2, U3: OPA1642AIDR; SOIC-8_3.9x4.9mm_P1.27mm; LCSC C126004
U4: Daisy Seed3; Electrosmith_Daisy_Seed

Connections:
+3V3A: TP12.1 (1_1), U4.21 (+3V3A)
+3V3D: C25.1, C31.1, J6.2, J10.4 (VDD), R25.1, R26.1, R27.1, R28.1, R29.1, R30.1, R31.1, R34.1, TP11.1 (1_1), U4.38 (+3V3D)
+9VA: C4.1, C22.1, C23.1, C24.1, R1.2, R16.1, TP10.1 (1_1), U1.8 (V+), U2.8 (V+), U3.8 (V+)
AIN1: C10.1, R8.2, TP3.1 (1_1), U4.16 (AUDIO_IN_1)
AIN2: C16.1, R15.2, TP6.1 (1_1), U4.17 (AUDIO_IN_2)
AOUT1: C19.1, U4.18 (AUDIO_OUT_1)
BATT-: J2.2, J4.2
ENC_A: C26.1, R27.2, SW1.A, U4.22 (A0/D15)
ENC_B: C27.1, R28.2, SW1.B, U4.23 (A1/D16)
ENC_SW: C28.1, R29.2, SW1.S1, U4.15 (D14)
FSW_L: C29.1, J7.1, R30.2, U4.32 (A10/D25)
FSW_R: C30.1, J9.1, R31.2, U4.28 (A6/D21)
GNDA: C4.2, C6.2, C7.2, C10.2, C12.2, C13.2, C16.2, C17.2, C18.2, C22.2, C23.2, C24.2, J1.3, J2.3, J5.1, J5.2, J8.3, NT1.1, R17.2, R22.2, TP13.1 (1_1), U1.4 (V-), U2.4 (V-), U3.4 (V-), U4.20 (AGND)
GNDD: C1.2, C2.2, C3.2, C25.2, C26.2, C27.2, C28.2, C29.2, C30.2, C31.2, D3.1 (A1), D4.1 (K), D5.1 (K), J3.2, J6.1, J6.6, J6.7, J7.2, J9.2, J10.6 (VSS), J10.9 (DET_B), J10.SH (SHIELD), NT1.2, SW1.C, SW1.S2, TP14.1 (1_1), U4.40 (DGND)
IN1_TIP: C5.1, J1.1, TP1.1
IN2_TIP: C11.1, J8.1, TP4.1
LED1: R32.1, U4.26 (A4/D19)
LED2: R33.1, U4.27 (A5/D20)
unnamed: C5.2, R2.1, R3.1
unnamed: C7.1, C8.1, R4.2, R5.1
unnamed: C8.2, R6.1
unnamed: C9.2, R7.2, R8.1, U1.7
unnamed: C11.2, R9.1, R10.1
unnamed: C13.1, C14.1, R11.2, R12.1
unnamed: C14.2, R13.1
unnamed: C15.2, R14.2, R15.1, U2.7
unnamed: C19.2, R18.1
unnamed: C20.2, R20.2, R21.1, U3.1
unnamed: C21.1, R21.2
unnamed: D1.2 (A), F1.2
unnamed: D2.2 (A), J4.1
unnamed: D4.2 (A), R32.2
unnamed: D5.2 (A), R33.2
unnamed: C21.2, J2.1, R22.1, TP8.1 (1_1)
unnamed: F1.1, J3.1
unnamed: J6.3, R23.2, R25.2
unnamed: J6.4, R24.2, R26.2
unnamed: R19.2, R20.1
unnamed: C6.1, R3.2, U1.3 (+)
unnamed: R4.1, TP2.1 (1_1), U1.1, U1.2 (-)
unnamed: C9.1, R6.2, R7.1, U1.6 (-)
unnamed: C12.1, R10.2, U2.3 (+)
unnamed: R11.1, TP5.1 (1_1), U2.1, U2.2 (-)
unnamed: C15.1, R13.2, R14.1, U2.6 (-)
unnamed: C20.1, R18.2, R19.1, U3.2 (-)
unnamed: C17.1, R16.2, R17.1, U3.5 (+)
OLED_RES: J6.5, U4.14 (D13)
SCL_U: R23.1, U4.12 (D11/SCL)
SDA_U: R24.1, U4.13 (D12/SDA)
SD_CD: J10.10 (DET_A), R34.2, U4.8 (D7)
SD_CLK: J10.5 (CLK), U4.7 (D6/SD_CLK)
SD_CMD: J10.3 (CMD), U4.6 (D5/SD_CMD)
SD_DAT0: J10.7 (DAT0), U4.5 (D4/SD_DAT0)
SD_DAT1: J10.8 (DAT1), U4.4 (D3/SD_DAT1)
SD_DAT2: J10.1 (DAT2), U4.3 (D2/SD_DAT2)
SD_DAT3: J10.2 (DAT3/CD), U4.2 (D1/SD_DAT3)
VIN: C1.1, C2.1, C3.1, D1.1 (K), D2.1 (K), D3.2 (A2), R1.1, TP9.1 (1_1), U4.39 (VIN)
VREF: C18.1, R2.2, R5.2, R9.2, R12.2, TP7.1 (1_1), U1.5 (+), U2.5 (+), U3.3 (+), U3.6 (-), U3.7

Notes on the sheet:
POWER — parallel diode-OR (pinmap §4n), no regulator. VIN abs max 17 V: 12 V adapters yes, 18 V no.
Rail = VIN (≈8.6 V battery / ≈11.6 V adapter). Battery − returns via the OUT ring (the power switch).
+9VA: RC-filtered op-amp rail (brief §3.4).
GROUND STAR — NT1 is the single AGND↔DGND join (pinmap §4l). Place at the power-entry corner.
DAISY SEED3 — pin numbers per daisy/board.h. Unused GPIO marked NC.
USB: the Seed's own USB-C port via the panel extender — no board connection (D29/D30 NC).
FRONT END CH A — Seed3 Fig 3.3 (RF stopper · unity follower · pole+pad · inverting unity · 100R+33n), Vref = rev D 2.7 V. Rin 1 M (K&K 24.5 nF → 6.5 Hz).
Second stage inverts → firmware flips the sign (brief §3.1).
FRONT END CH B — Seed3 Fig 3.3 (RF stopper · unity follower · pole+pad · inverting unity · 100R+33n), Vref = rev D 2.7 V. Rin 1 M (K&K 24.5 nF → 6.5 Hz).
VREF — rev D bias: 1 M / 470 k from +9VA → 2.7 V. Buffered by U3B.
OUTPUT — Seed3 Fig 3.6 instrument-level stage, UNITY (Rin = Rf1 15k, Rf2 0R link; fit 18k for +7 dB). 100R source, 10u/10k out. OUT ring = battery −.
OP-AMP POWER — +9VA / AGND, 100n at each chip.
OLED 1.3" SH1106 I²C module on a 7-pin socket. DC + CS hard to GND → 0x3C (board.h). 33R series at the Seed, 4k7 pull-ups at the header (brief §3.6).
ENCODER — PEC11R, board-mounted. A/B/SW pulled up 10k, 10n debounce. ⚠ bushing must not bond to the casting (brief §2).
FOOTSWITCHES — panel-mounted momentary SPST on JST 2-pin leads. 10k pull-up + 100n. LEFT = bypass (D25), RIGHT = tuner (D21).
STATUS LEDs — D19 = bypass/engaged, D20 = looper/record. 3 mm through the face; shape/position distinguish them, not colour.
microSD — push-push socket ON THE SDMMC PINS (D1–D6). Bit-bang SPI fallback = 4 pin numbers in sd_spi.h: CS=D1 MOSI=D5 SCK=D6 MISO=D4 (brief §3.7).
TEST POINTS — every pad has an adjacent GND pad on the layout (feedback_design_for_probeability).

Board: 2 copper layers, 101 parts (9 on the bottom side), 58 nets, no tracks yet.

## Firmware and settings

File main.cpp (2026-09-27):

// Tone Trixter — Daisy Seed3 bring-up diagnostics.
//
// Purpose: prove the board is alive and correctly wired BEFORE any audio or DSP code exists.
// Every check here answers one question and reports pass/fail on its own, so a failure points at
// a specific joint rather than "it doesn't work".
//
// This follows the project's hard-won bench rule: separate the variables. On the Pico build,
// three separate faults (a compressor left on, an uncompensated probe, a debug probe radiating
// into a high-Z input) each produced a believable-but-wrong answer because more than one thing
// was in play at once. Diagnostics exist to make that impossible.
//
// Flash:  make program-dfu   (hold BOOT, tap RESET, then run)
// Watch:  screen /dev/tty.usbmodem* 115200   — or any serial terminal at 115200

#include "daisy_seed.h"
#include "board.h"

// ⚠ NO extern "C" wrapper: dsp_chain.cpp compiles as C++ here, so both sides must agree on
// linkage. The header is C-style but the translation unit is C++.
#include "audio/dsp_chain.h"
#include "audio/biquad.h"
#include "audio/tt_store.h"
#include "audio/wav_load.h"
#include "audio/tuner.h"
#include "audio/menu.h"
#include "audio/app_hooks.h"
#include "audio/oled_shim.h"
#include "audio/backing.h"
#include "audio/usb_msc.h"
#include "audio/looper.h"
extern "C" {
#include "ff.h"
#include "ff_gen_drv.h"
extern const Diskio_drvTypeDef tt_sd_driver;
}
#include "TwoStageFFTConvolver.h"

#include <cstdio>
#include <cmath>
#include <cstring>
#include <strings.h>   // strcasecmp
#include <cstdlib>

// ---------------------------------------------------------------------------------------------
// printf → USB console. dsp_chain.cpp (shared with the Pico) reports through printf; on the Pico
// that is the UART, here newlib's default _write is a stub that drops everything -- so `dump`,
// `eq.hi_gain 2` etc. changed the chain and printed nothing (found 2026-09-18). Route stdout to
// the same CDC logger PrintLine() uses, a line at a time so the terminal gets CR LF.
// ⚠ Foreground only: the logger is not interrupt-safe, and neither is anything that printf()s.
extern "C" int _write(int fd, const char* buf, int len)
{
    static char line[160];
    static int  n = 0;
    (void)fd;
    for(int i = 0; i < len; i++)
    {
        const char c = buf[i];
        if(c == '\n' || n == (int)sizeof(line) - 1)
        {
            line[n] = 0;
            daisy::Logger<daisy::LOGGER_INTERNAL>::PrintLine("%s", line);
            n = 0;
            if(c != '\n') line[n++] = c;
        }
        else if(c != '\r')
            line[n++] = c;
    }
    return len;
}

using namespace daisy;

static DaisySeed hw;

// ---------------------------------------------------------------------------------------------
// OLED readout.
//
// ⚠ THIS EXISTS SO THE BOARD CAN BE DIAGNOSED WITHOUT USB. Audio work must run from the 9 V jack:
// on USB the Daisy back-feeds VIN to ~4.9 V, which puts the op-amp daughter's Vref (1.57 V) ABOVE
// its common-mode ceiling (1.41 V) -- the exact out-of-spec condition that measured 8.9 % THD on
// the 5 V build. Every audio result taken on USB power would be wrong, and wrong in a way that
// looks like a front-end fault. The serial console only exists on USB, so it cannot be the way the
// board reports during audio testing.
static bool oled_ok = false;

// Boot-check results, kept so a short press of the encoder switch can re-print them. ⚠ The boot
// report itself is routinely LOST: StartLog(false) starts printing before the USB CDC device has
// enumerated, so the host attaches mid-banner and everything before that point never arrives
// (seen as "===========$$"). On-demand re-print is the fix; blocking on the host is not.
static bool g_board_ok = false, g_i2c_ok = false, g_sd_ok = false;

// ---------------------------------------------------------------------------------------------
// Audio passthrough + input meter.
//
// AUDIO IN 1 -> AUDIO OUT 1 and 2, unmodified. No DSP, no gain: this measures the ANALOGUE PATH
// and nothing else, so anything it shows is the front end, the jacks or the codec.
//
// ⚠ Test the codec BEFORE the daughter is fitted, by linking daughter pin 4 (gate-in) to pin 3
// (out) in the socket. That bypasses the buffer and proves the Daisy's own audio in/out. Fit the
// daughter after, and any change is unambiguously the front end.
//
// ⚠ 0 dBFS here is the CODEC's full scale (±1.8 V at the pin), NOT the buffer's clean limit. The
// op-amp daughter rev D clears ~2.5 V at a 8.86 V rail, so the converter clips first -- which is
// the intended design, clipping in the fixable place rather than the buffer.
// ---- DSP chain, ported from the RP2350 build ----------------------------------------------
//
// dsp_chain.cpp, biquad.h and the HiFi-LoFi FFTConvolver compiled for the H750 with NO changes --
// the Pico implementation was written against stdio/string/stdlib/math only.
//
// ⚠ ORDER MATTERS, and it matches the Pico: IR convolution FIRST, then the chain
// (EQ -> Dynamics -> Output level). See dsp_chain.h and pico/main.cpp:1622.
//
// ⚠ DEFAULT BOOT STATE IS COMPLETE PASSTHROUGH -- global bypass on, no IR. The pedal always starts
// transparent, so anything measured at boot reflects the FRONT END ALONE with no DSP on top of it.
// That matters while the analogue path is still being characterised.
//
// ⚠ The IR is NOT embedded. It lives on the SD card and is loaded when a preset asks for one, so
// nothing here costs flash until it is actually wanted.
static fftconvolver::TwoStageFFTConvolver g_convolver;

// ---- SD card: presets and IRs ---------------------------------------------------------------
//
// ⚠ Everything here is OPTIONAL. No card, no presets, no IR -- the pedal still boots and passes
// audio. A missing SD card must never be the difference between a working pedal and a dead one.
static FATFS g_fs;
static char  g_sd_path[4]     = {0};
static bool  g_sd_mounted     = false;
static int   g_preset_count   = 0;

// ⚠ 4096 taps of scratch, matching the Pico's SD_IR_MAX_TAPS. The convolver COPIES the IR in, so
// this buffer is only needed during load -- but it stays static because 16 KB on the stack would
// overflow it.
static constexpr int kIrMaxTaps = 4096;
static float         g_ir_buf[kIrMaxTaps];
static int           g_ir_len  = 0;
static char          g_ir_name[24] = "none";

// ⚠ The OUTCOME of the SD phase, captured as it happens. The boot report is routinely lost to USB
// CDC enumeration, so a failure reason that only prints at boot is a reason nobody reads. This has
// now bitten three times (block size, the SD check, and the SD result itself) -- so the rule is:
// every check records its verdict here, and PrintFullReport() shows it.
static char g_sd_status[64] = "not attempted";
static int  g_preset_idx = 0;

// ⚠ libDaisy's Encoder owns A/B/SW and does the quadrature decoding. The raw-GPIO monitoring that
// proved those joints during bring-up has served its purpose -- keeping both would fight over the
// pins. Footswitches stay raw GPIO.
static Encoder g_enc;

// Tuner. ⚠ Fed from the RAW INPUT, before any DSP: you tune the string, not the compressed and
// EQ'd version of it. Gated behind g_tuner_on so its autocorrelation costs nothing when unused --
// on the Pico the equivalent was a `tuner on/off` command for the same reason.
static volatile bool g_tuner_on = false;
static bool          g_gr_on    = true;    // GR band on the home screen

// ⚠ METER REPAINTS ARE AN EMI SOURCE. Every home-screen refresh drives an I2C burst on SDA/SCL, and
// on this layout the audio-in run passes within a few pitches of them -- ~12.7 mm of exposed 1 MOhm
// node, which the pinmap already flagged as the thing to suspect first if pickup showed up. It has:
// a low blip in time with the meter refresh, and a buzz on menu changes (2026-09-09).
//
// The same fault ran the V1 build, where the GR meter shipped defaulting OFF for exactly this reason
// ([[project_home_gr_meter_crosstalk]]). The real fix is layout -- a ground guard between the audio
// run and the I2C pair -- but the cheap firmware lever is to repaint LESS.
//
// ⚠ `meters off` freezes the periodic repaint entirely: the home screen then updates only on a real
// event (preset change, footswitch, encoder), so a silent pedal sends NOTHING on the bus. That is
// the state to measure in -- you cannot characterise a noise floor while the display is repainting
// into the input.
static bool g_meters_on = true;

// ⚠ STATS SCREEN — LONG PRESS from home, short click to leave.
//
// ⚠ Long press beats double-click here, and the reason is latency. A double-click can only be
// detected by DEFERRING the first click, which put ~300 ms on every menu-open. A long press is
// resolved from the duration the button was already held, so a short click still acts the instant
// it is released and nothing is delayed. It also matches the gesture already on this pedal:
// hold 2 s = DFU.
//
// Thresholds are chosen so there is NO dead zone and no way to trip DFU by accident:
//     release < 2000 ms    -> click   (open the menu / select)
//     release 2000-4000 ms -> stats (panel shows "release for STATS")
//     held 4000-5000 ms    -> DFU countdown ("release to cancel"), no action on release
//     held    >= 5000 ms   -> DFU, which fires WHILE HELD, so holding
//                           past the stats window never also opens stats.
//
// ⚠ Note the tension: this screen repaints, so reading it is not a silent-bus state. It is for
// checking bk underruns and CPU without a laptop -- NOT for judging crosstalk. Use `meters off`.
static bool               g_stats_screen = false;
static constexpr uint32_t kStatsHoldMs   = 2000;   // release after this -> stats
static constexpr uint32_t kStatsMaxMs    = 4000;   // ...and before this
static constexpr uint32_t kDfuHoldMs     = 5000;   // ⚠ 5 s, not 2. DFU is barely used -- the normal
                                                   // flow is `make flash-wait` then a power cycle --
                                                   // so it has no business owning the short end of
                                                   // the hold, where the useful gestures live.

// ⚠ File-scope so the `i2c` command can re-initialise the bus at runtime. Kept together because
// re-initing the controller without re-initing the panel leaves the SH1106 half-configured.
static I2CHandle         g_i2c_h;
static I2CHandle::Config g_i2c_cfg;
static int               g_i2c_khz = 400;

static bool SetI2cKhz(int khz);   // defined below, once g_oled_dirty is in scope

// ⚠ 1000 ms, was 500. Halves the repaint rate, and the meters are glanceable data rather than
// something you track continuously -- the tuner is what you watch, and it has its own 100 ms branch.
static constexpr uint32_t kHomeRefreshMs = 1000;
static bool          g_in_menu  = false;

// ⚠ The menu times out back to the home screen. A pedal left sitting in a settings screen shows
// nothing a player needs mid-song -- no level, no preset, no clip indicator -- and the one moment
// you would notice that is the moment you cannot do anything about it. Any encoder activity
// restarts the clock, so it only fires when the menu has genuinely been abandoned.
static constexpr uint32_t kMenuIdleMs = 5000;
static uint32_t           g_menu_at   = 0;
static bool          g_oled_dirty = true;

// ⚠ TIMING INSTRUMENTATION. Several rounds of guessing at "the menu is stuck" produced fixes that
// each helped a little and none of which settled it. These record the WORST case seen for each
// stage of the foreground loop, so the next report says which one actually costs the time instead
// of us both reasoning about it. Reset with the `times` command.
static volatile uint32_t g_t_flush   = 0;   // us, worst oled_flush()
static volatile uint32_t g_t_render  = 0;   // us, worst menu_render()
static volatile uint32_t g_t_service = 0;   // us, worst backing_service()
static volatile uint32_t g_t_loop    = 0;   // us, worst whole iteration (work only)
// ⚠ PERIOD between iteration starts -- catches anything the work timer cannot, including
// System::Delay() and any stall between passes. If a hang shows here but not in g_t_loop, the time
// is going somewhere outside the instrumented work.
static volatile uint32_t g_t_period  = 0;   // ⚠ MILLISECONDS, not us -- see below
static volatile uint32_t g_t_wraps   = 0;   // discarded samples, evidence of the wrap

// ⚠ CPU LOAD, measured in the audio callback against the block period.
//
// "How much budget is left" is the question that decides whether the next feature fits, and it is
// the one thing no amount of listening can answer -- a chain at 95% sounds exactly like one at 40%
// right up until it does not, and then it is a dropout under a heavy strum rather than a gradual
// warning. Measured, it becomes a number on the home screen.
//
// ⚠ System::GetTick() deltas ARE wrap-safe -- it is the raw 32-bit counter and unsigned subtraction
// handles the wrap. That is NOT true of GetUs(), which divides the counter down and so wraps
// dirtily every ~21.5 s (see CLAUDE.md). Use ticks here, not microseconds.
static volatile float    g_cpu_avg = 0.f;   // % of the block period, smoothed
static volatile float    g_cpu_pk  = 0.f;   // worst single block since reset
static uint32_t          g_ticks_per_block = 0;
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
int main(void)
{
    hw.Init();

    // ⚠ USB DRIVE MODE is decided FIRST -- before the CDC logger takes the USB port.
    if(BootGestureUsbDrive())
        UsbDriveMode();                     // never returns
    // ⚠ StartLog(FALSE) -- do NOT wait for a PC.
    //
    // StartLog(true) blocks until a terminal opens, which means on a 9 V supply with no USB the
    // board hangs here forever and never reaches the diagnostics at all. That made the onboard LED
    // useless as a "did it boot" indicator on battery/adapter power (2026-09-05).
    //
    // The boot report is instead REPEATED periodically in the monitor loop, so a terminal attached
    // at any time still sees the results. Better than blocking: the board always runs.
    hw.StartLog(false);
    setvbuf(stdout, NULL, _IONBF, 0);   // printf → _write immediately, not at 1 kB (see _write above)
    hw.usb_handle.SetReceiveCallback(UsbRx, UsbHandle::FS_INTERNAL);

    // Heartbeat immediately, before anything that could block or fail, so the LED proves the board
    // booted even with no console attached at all.
    for(int i = 0; i < 6; i++)
    {
        hw.SetLed(i % 2 == 0);
        System::Delay(80);
    }
    hw.SetLed(false);

    // ⚠ SYNC PREAMBLE for the CDC enumeration race. StartLog(false) prints before the host's USB
    // CDC is up, so the first bytes are dropped/garbled ("===$$"). We can't wait for a connect flag
    // (libDaisy's CDC never exposes one), so instead: a short settle, then a run of THROWAWAY
    // newlines -- if enumeration finishes during these, the banner below lands intact. It does not
    // block on the host, so battery/adapter boot is unaffected (2026-09-27).
    System::Delay(400);
    for(int i = 0; i < 6; i++)
        hw.PrintLine("");

    hw.PrintLine("=============================================");
    hw.PrintLine(" Tone Trixter -- Daisy Seed3 bring-up");
    hw.PrintLine(" built " __DATE__ " " __TIME__);
    hw.PrintLine("=============================================");

    int failures = 0;

    hw.PrintLine("");
    hw.PrintLine("[1] board identity");
    bool board_ok = CheckBoard();
    hw.PrintLine("  %s", board_ok ? "PASS" : "FAIL -- expected Daisy Seed3");
    g_board_ok = board_ok;
    failures += board_ok ? 0 : 1;

    hw.PrintLine("");
    hw.PrintLine("[2] I2C1 bus scan (SCL=D%d SDA=D%d)", tt::kOledScl, tt::kOledSda);
    I2CHandle&        i2c = g_i2c_h;      // file-scope, so `i2c <khz>` can re-init it live
    I2CHandle::Config& cfg = g_i2c_cfg;
    cfg.periph         = I2CHandle::Config::Peripheral::I2C_1;
    cfg.speed          = I2CHandle::Config::Speed::I2C_400KHZ;
    cfg.mode           = I2CHandle::Config::Mode::I2C_MASTER;
    cfg.pin_config.scl = tt::P(tt::kOledScl);
    cfg.pin_config.sda = tt::P(tt::kOledSda);

    // ⚠ DRIVE THE OLED'S RESET PIN BEFORE TOUCHING THE BUS.
    //
    // RES (D13) is ACTIVE LOW. Left as an unconfigured input it floats, and the SH1106 comes out of
    // reset -- or does not -- differently on each power-up. That is an intermittent that jiggling
    // cannot reproduce, because it is not mechanical.
    //
    // ⚠ It was masked until 2026-09-05 by StartLog(true), which blocked for SECONDS waiting for a
    // terminal and gave the pin ample time to drift high. Switching to StartLog(false) cut that to
    // ~480 ms and the intermittent appeared. The delay was never the fix -- it was the disguise.
    //
    // Assert reset, hold, release, then let the controller come up before addressing it. The pin is
    // left DRIVEN HIGH afterwards, never floating.
    static GPIO oled_res;
    oled_res.Init(tt::P(tt::kOledRes), GPIO::Mode::OUTPUT);
    oled_res.Write(false);
    System::Delay(10);
    oled_res.Write(true);
    System::Delay(50);

    bool i2c_ok = false;
    if(i2c.Init(cfg) != I2CHandle::Result::OK)
        hw.PrintLine("  I2C init FAILED");
    else
        i2c_ok = ScanI2c(i2c);
    hw.PrintLine("  %s", i2c_ok ? "PASS" : "FAIL");
    g_i2c_ok = i2c_ok;
    failures += i2c_ok ? 0 : 1;

    if(i2c_ok)
    {
        // ⚠ Our own SH1106 driver, not libDaisy's -- see audio/oled_shim.cpp for why (libDaisy
        // sends one I2C transaction PER BYTE, ~77 ms a frame, which starved the whole foreground
        // loop). It borrows the already-configured bus rather than re-initialising it.
        tt_oled_init(i2c, tt::kOledI2cAddr);
        oled_ok = true;
        menu_init();
        hw.PrintLine("  display initialised (batched page writes)");
        OledBoot("starting...");
    }


    hw.PrintLine("");
    OledBoot("inputs");
    hw.PrintLine("[3] digital inputs -- all active LOW, internal pull-ups");

    for(size_t i = 0; i < kNumInputs; i++)
        inputs[i].gpio.Init(tt::P(inputs[i].pin), GPIO::Mode::INPUT, GPIO::Pull::PULLUP);

    g_enc.Init(tt::P(tt::kEncA), tt::P(tt::kEncB), tt::P(tt::kEncSw));

    // ⚠ A and B are read by EncoderPoll(), not by libDaisy's broken decode. g_enc keeps the click.
    // Two GPIO objects on one pin is harmless -- both configure it identically and only read it.
    g_enc_a.Init(tt::P(tt::kEncA), GPIO::Mode::INPUT, GPIO::Pull::PULLUP);
    g_enc_b.Init(tt::P(tt::kEncB), GPIO::Mode::INPUT, GPIO::Pull::PULLUP);
    System::Delay(2);   // let the pull-ups settle before sampling the rest state
    g_q_rest = (uint8_t)((g_enc_a.Read() ? 2 : 0) | (g_enc_b.Read() ? 1 : 0));
    g_q_prev = g_q_rest;
    hw.PrintLine("  encoder rest state A/B = %d%d", (g_q_rest >> 1) & 1, g_q_rest & 1);

    // ⚠ 10 kHz sampler. Prescaler is 0 out of Init(), so GetFreq() reports the raw 2x-PClk1 tick
    // rate; dividing that down to 1 MHz and reloading every 100 ticks lands on 10 kHz whatever the
    // core clock is, rather than hard-coding a number that a boost-clock change would silently
    // falsify.
    TimerHandle::Config tcfg;
    tcfg.periph     = TimerHandle::Config::Peripheral::TIM_4;
    tcfg.dir        = TimerHandle::Config::CounterDir::UP;
    tcfg.period     = 0xffff;
    tcfg.enable_irq = true;
    if(g_enc_tim.Init(tcfg) == TimerHandle::Result::OK)
    {
        const uint32_t base = g_enc_tim.GetFreq();          // ticks/s with PSC = 0
        g_enc_tim.SetPrescaler((base / 1000000u) - 1u);     // -> 1 MHz
        g_enc_tim.SetPeriod(99);                            // -> 10 kHz
        g_enc_tim.SetCallback(EncTick, nullptr);
        g_enc_tim.Start();
        hw.PrintLine("  encoder sampler: TIM4 @ 10 kHz (base %lu Hz)", (unsigned long)base);
    }
    else
    {
        hw.PrintLine("  ⚠ encoder sampler FAILED to init -- detents will be missed");
    }
    tuner_init(48000.f);

    // ⚠ Init ALL pins, then settle, THEN read. Reading straight after Init() returns the pin's
    // pre-pull-up state and every input reports a false LOW -- observed on the first hardware run
    // 2026-09-05, where all five read LOW here and then immediately reported "released" in the
    // monitor loop below. The pins were not even wired yet, so a short was impossible: the
    // diagnostic was lying about the board, which is precisely what it exists to prevent.
    System::Delay(10);

    for(size_t i = 0; i < kNumInputs; i++)
    {
        inputs[i].last = inputs[i].gpio.Read();
        hw.PrintLine("  D%-2d %-14s idle=%s",
                     inputs[i].pin,
                     inputs[i].name,
                     inputs[i].last ? "HIGH (ok)" : "LOW  <- shorted to ground, or held down");
    }
    hw.PrintLine("  (HIGH is also what an UNCONNECTED pin reads. Until the encoder and");
    hw.PrintLine("   footswitches are wired this proves the pull-ups, not the wiring.)");

    hw.PrintLine("");
    OledBoot("microSD");
    hw.PrintLine("[4] microSD -- bit-banged SPI, CMD0");
    bool sd_ok = TestSd();
    hw.PrintLine("  %s", sd_ok ? "PASS" : "FAIL (expected until the card + module are in)");
    g_sd_ok = sd_ok;
    failures += sd_ok ? 0 : 1;

    hw.PrintLine("");
    OledBoot("audio");
    hw.PrintLine("[5] audio passthrough");
    // ⚠ Do NOT call SetAudioSampleRate here. 48 kHz is already libDaisy's default, the working
    // passthrough never called it, and the seed3-updates branch modifies sai.h -- so it is a new
    // variable touching the SAI for no benefit. Removed 2026-09-05 while chasing silent output.
    hw.SetAudioBlockSize(kBlock);

    // ⚠ Unity output level and global bypass ON: complete passthrough at boot, by design.
    dsp_chain_init(48000.f, 1.0f);
    biquad_highpass(&g_dry_hp, 48000.f, 2500.f, 0.707f);   // dry-blend high-pass (see g_ir_dry)
    g_dsp_bypass = true;
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

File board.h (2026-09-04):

// Tone Trixter — Daisy Seed3 board pin map.
//
// SINGLE SOURCE OF TRUTH for firmware pin numbers. These are Daisy "D" numbers as printed on the
// Seed3 pinout, and they are derived from the board layout generator in the private repo
// (private/docs/gen_daisy_board_svg.py) — NOT from the hand-maintained tables in the pinmap doc,
// which have drifted twice. If a pin here disagrees with a document, the generator wins.
//
// Board: 18 cols x 45 rows, Adafruit 1606 cut down. Daisy under-mounted on rows 10-29.
// Row-to-pin relation used below: side A row = 9 + pin, side B row = 50 - pin.

#pragma once

#include "daisy_seed.h"

namespace tt
{
// ---------------------------------------------------------------- OLED (SH1106, 1.3", I2C)
// Board rows 19-25 on col 3. Rows 19/20/24/25 are CUT from the Daisy strip and jumpered; rows
// 21-23 ride their traces straight to the Daisy pins below.
constexpr uint8_t kOledScl = 11; // D11 · I2C1 SCL   (row 21, rides the trace)
constexpr uint8_t kOledSda = 12; // D12 · I2C1 SDA   (row 22, rides the trace)
constexpr uint8_t kOledRes = 13; // D13             (row 23, rides the trace)

// I2C address is STRAPPED, not selected. The module's DC pin is cut free at col 3 row 24 and tied
// to the digital-ground spine, because encoder SW1 owns D14 on that same row.
//
// ⚠ DO NOT drive a DC pin from firmware. There is no GPIO on it — it is hard-tied to ground.
// To move the display to 0x3D later, re-target that one jumper to the +3V3D rail instead.
constexpr uint8_t kOledI2cAddr = 0x3C;

// ---------------------------------------------------------------- Rotary encoder (PEC11R)
// Body rows 30-35, turned 90 degrees so the three in-line terminals land on separate strips.
// A/C/B on col 12 rows 31/32/33; SW1/SW2 on col 6 rows 31/33. C and SW2 go to the DGND rail,
// so A, B and SW1 all read LOW when active and need pull-ups.
constexpr uint8_t kEncA  = 15; // A0 / D15  (row 28)
constexpr uint8_t kEncB  = 16; // A1 / D16  (row 27)
constexpr uint8_t kEncSw = 14; // D14       (row 24) — ⚠ see kOledI2cAddr above

// ---------------------------------------------------------------- Footswitches
// NOT on the perfboard. Panel-mounted in the enclosure face toward the player and wired back by
// flying leads: signal into col 14, ground into the DGND rail at col 17, same row. No cut needed.
constexpr uint8_t kFswBypass = 25; // A10 / D25 (row 18)
constexpr uint8_t kFswTuner  = 21; // A6  / D21 (row 22)

// ---------------------------------------------------------------- microSD (bit-banged SPI)
// Header col 6, rows 11-17. ⚠ These deliberately do NOT sit on the SPI1 peripheral: the breakout
// presents a fixed pin order that no hardware SPI instance matches, so it must be bit-banged.
// Rows 13 and 15 are cut and jumpered to power, hence the gaps in the D-numbers.
//
// ⚠ Breakout silkscreen is CARD-referenced: its "DO" is data OUT of the card = MISO at the host,
// and "DI" is data IN = MOSI. Do not wire them by name alone.
constexpr uint8_t kSdCs   = 1; // D1 (row 11)
constexpr uint8_t kSdMosi = 2; // D2 (row 12) — breakout "DI"
constexpr uint8_t kSdSck  = 4; // D4 (row 14)
constexpr uint8_t kSdMiso = 6; // D6 (row 16) — breakout "DO"
constexpr uint8_t kSdCd   = 7; // D7 (row 17) — card detect, optional

// ---------------------------------------------------------------- Audio
// Handled by libDaisy's SAI setup, listed here for reference only.
// AUDIO IN 1 = pin 16 (row 25) · AUDIO OUT 1 = pin 18 (row 27).
// The front end is the op-amp daughter rev D on the 9 V rail; the Seed3 input is AC-coupled and
// accepts +/-1.8 V, so the daughter drives it through a link (R1) with a 100k DC return (R2).

inline daisy::Pin P(uint8_t d)
{
    return daisy::DaisySeed::GetPin(d);
}

} // namespace tt

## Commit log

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2026-09-04 First firmware: Seed3 bring-up diagnostics, builds clean
    Takes the repo from scaffold to a linking Seed3 target (81 KB of 128 KB
    flash). Not yet flashed -- the board is mid-assembly.
    ⚠ libDaisy: Seed3 support is NOT on main. Main's BoardVersion enum stops at
    DAISY_SEED_2_DFM and the tree has zero TAC5242 references, so a stock libDaisy
    would configure the wrong codec. The seed3-updates branch adds DAISY_SEED_1_2
    and DAISY_SEED_3 in a small focused diff (~76 lines over daisy_seed.h/.cpp and
    sai.h/.cpp). Pinned to e1f740a rather than tracking the tip, since an unmerged
    branch can be rebased or force-pushed underneath us.
    Two things that diff settles:
    - Seed3 is detected at RUNTIME (PH6 tie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
    [board.h, main.cpp]
2026-09-05 Fix false LOW on every digital input: settle pull-ups before first read
    First hardware run (Seed3 standalone, nothing wired) reported all five inputs
    LOW at idle -- "stuck? check for a short to ground" -- and then immediately
    printed "released" for all five in the monitor loop.
    Cause was in the diagnostic, not the board: Init() and Read() were called
    back-to-back per pin, so the first read returned the pre-pull-up state. With
    the Daisy not yet on the main board there was no wire to short, which is what
    made it conclusive.
    Fix: init every pin, System::Delay(10), then read the idle states.
    ⚠ Worth keeping: the diagnostic lied about the board, which is exactly the
    failure it exists to prev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
    [main.cpp]
2026-09-05 Sleep the core with __WFI(): STM32 ran painfully hot in the idle loop
    On the 2026-09-05 bring-up the STM32H750 got hot enough to be painful on
    sustained contact, with the Seed3 standalone and the firmware doing nothing
    but polling five GPIOs.
    Cause: System::Delay() is HAL_Delay(), which BUSY-WAITS. The core sat at
    400 MHz spinning to do nothing. Replaced with __WFI(), which sleeps until the
    next interrupt -- safe because libDaisy defines SysTick_Handler() at 1 kHz, so
    a wake source is never more than 1 ms away. ⚠ Without a periodic interrupt
    __WFI() would hang instead.
    Measured, same board and supply, one variable changed:
    System::Delay(1) -> painful to touch
    __WFI() -> sl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
    [main.cpp]
2026-09-05 Settle fix confirmed on hardware; revert __WFI() -- it kills the USB console
    Second hardware run. The pull-up settle fix WORKS: all five digital inputs now
    correctly read HIGH at idle, where before they all reported a false LOW.
    Reverting __WFI() and accepting the heat. Measured, same board and supply:
    System::Delay(1) painful to touch USB console stays connected
    __WFI() slightly warm screen disconnects at loop entry
    bootloader (DFU) cool n/a
    ⚠ The obvious cause is ruled out. libDaisy's USB suspend callback sets
    SLEEPDEEP and SLEEPONEXIT (src/usbd/usbd_conf.c:314), which would turn __WFI()
    into STOP mode and gate the USB clocks -- but clea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
    [main.cpp]
2026-09-05 Never block on a console: StartLog(false) + LED boot signal
    On a 9 V supply with no USB the board hung before the diagnostics ran at all,
    because StartLog(true) blocks until a PC opens the port. That made the onboard
    LED useless as a "did it boot" indicator on adapter or battery power -- the one
    situation it was most needed.
    - StartLog(false): the board always runs, console or not.
    - 6 fast LED flashes immediately after Init(), before anything that can block
    or fail, as an unconditional "booted" signal.
    - The verdict now re-prints every 5 s in the monitor loop, so a terminal
    attached at ANY time sees the state. That removes the reason StartLog(true)
    existed -- the boot report is no lo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
    [main.cpp]
2026-09-05 Board bring-up complete: OLED reset fix, microSD CMD0 test, full summary line
    All digital peripherals verified on hardware, both supplies: Seed3 detected,
    OLED answering at 0x3C, microSD CMD0 = 0x01, encoder A/B showing correct
    quadrature (lead/lag swaps with direction), SW working, no shorts.
    Three changes:
    1. ⚠ DRIVE THE OLED'S RESET PIN. RES (D13) is active low and was left as an
    unconfigured input -- floating, so the SH1106 came out of reset or did not,
    differently each power-up. Masked until today by StartLog(true) blocking for
    seconds; StartLog(false) cut that to ~480 ms and exposed it as an
    intermittent that JIGGLING COULD NOT REPRODUCE, because it was never
    mechani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
    [main.cpp]
2026-09-05 Report microSD card-detect in the summary line
    Card detect was the one SD line still unverified, and it was printed only in
    the boot report -- which StartLog(false) makes unreadable, since the board
    prints before USB CDC enumerates.
    Now appears in the repeating 5-second line as cd=HIGH / cd=LOW, so a
    card-in/card-out pair actually shows whether that line works.
    ⚠ Read at boot, so power-cycle with the card in each position rather than
    hot-swapping.
    ⚠ If it does not change, that is not necessarily a fault -- some breakouts do
    not populate the detect contact. Check the datasheet before chasing it.
    Same trap as check 4 itself: a result that is not in the repeating line is
    invisible in pr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
    [main.cpp]
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2026-09-05 OLED readout, hold-to-DFU, and an on-demand report
    Three additions, all aimed at the same problem: the board needs to be
    diagnosable without depending on a USB console.
    1. OLED readout -- 8 lines at 2 Hz showing all four checks plus live input
    state. ⚠ This is the only readout with no cable attached, which is what
    matters once the enclosure is closed. It also removes the reason audio
    testing would need USB: on USB the Daisy back-feeds VIN to ~4.9 V, putting
    the op-amp daughter's Vref (1.57 V) ABOVE its common-mode ceiling (1.41 V) --
    the same out-of-spec condition that measured 8.9 % THD on the 5 V build.
    ⚠ Line 6 is a REMINDER, not a measurement: the board cannot read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
    [main.cpp]
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2026-09-05 DSP port verified on hardware; instrument the audio engine
    Passthrough confirmed working through the ported chain: 48 kHz, block 64,
    running from SRAM with the FFTConvolver compiled in and global bypass on.
    The silence chased through several flash cycles was a MARGINAL OUTPUT JACK TIP
    CONTACT, not firmware. ⚠ Recorded because the diagnosis was instructive:
    - Continuity tracing said the outputs were correct, and they were. It tests the
    BOARD WIRING -- it cannot test the lug making contact with a PLUG under
    insertion force, which is a different joint and the one that was failing.
    "Traced correct" and "works with a cable in" are separate claims.
    - ⚠ The jack is now the least reliabl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
    [main.cpp]
2026-09-05 SD presets and IR loading, ported from the RP2350 build
    sd_spi.c, sd_diskio.c, tt_store.cpp and wav_load.c now build for the Seed3.
    Links clean at 146 KB of 480 KB SRAM.
    ⚠ sd_spi.c is SHIMMED, NOT REWRITTEN. It is 229 lines of SD protocol -- command
    framing, the CMD0/CMD8/ACMD41 dance, CSD parsing, timeouts -- and only a handful
    of GPIO calls under it are Pico-specific. sd_daisy_shim.h maps those onto
    libDaisy so the driver source stays IDENTICAL between both builds and a protocol
    fix on either platform applies to both. Rewriting would fork the file and
    guarantee they drift. Pins remapped to Daisy D numbers: CS=D1, MOSI=D2, SCK=D4,
    MISO=D6, CD=D7.
    ⚠ sd_diskio.c registers a Diskio_drvTy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
    [main.cpp, sd_daisy_shim.cpp, sd_spi.c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]
2026-09-06 Preset cycling and IR loading working on hardware
    The pedal now loads presets and IRs from the SD card and switches between them.
    Confirmed on hardware: 3 presets read, installed, and selectable.
    Two fixes to get there:
    ⚠ INSTALLING presets is not the same as READING them. tt_store_load() reads the
    card; dsp_chain_install_presets() hands them to the chain. Without the second
    call dsp_chain_find_preset() searches the BUILT-IN table and returns -1 for
    every name on the card -- which silently produced "3 presets, no IR" and looked
    like an IR-loading fault. Also added the Pico's fallback: if the named boot
    preset is missing, use the FIRST rather than none.
    ⚠ The tuner footswitch now cycle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
    [main.cpp]
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2026-09-06 Port the encoder menu
    menu.cpp and menu.h ported UNCHANGED. It used only three of the Pico OLED
    driver's functions -- oled_clear, oled_text, oled_text_inv -- so oled_shim.cpp
    provides those on libDaisy's OledDisplay and the menu compiles as-is. Same
    reasoning as the SD driver shim: a layout fix on either platform then applies to
    both instead of the two versions drifting.
    ⚠ oled_text_inv is a filled bar plus text drawn "off". libDaisy has no
    inverted-text call, and the selected row depends on it to be readable at a
    glance -- without it every row looks identical and the menu is unusable.
    ⚠ The Pico's async/DMA flush machinery is deliberately NOT reproduced. It
    existed because the RP2350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
    [main.cpp, menu.cpp, oled_shim.cpp]
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2026-09-06 Fix the display bottleneck, move the tuner off the audio thread, add commands
    ⚠ ROOT CAUSE of four reported bugs at once: libDaisy's SSD130xI2CTransport
    sends ONE BLOCKING I2C TRANSACTION PER BYTE -- 1024 for a 128x64 frame, about
    77 ms per flush. With the menu redrawing at 100 ms the foreground loop was ~77 %
    blocked, which explains the sluggish menu, the encoder missing clicks
    (Debounce starved), and the backing track breaking up (backing_service
    starved). The home screen redrew at 500 ms and was fine -- that asymmetry is
    what pointed at the display rather than at the four subsystems that looked
    broken.
    audio/oled_shim.cpp is now our own SH1106 driver writing a whole PAGE per
    transactio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
    [main.cpp, menu.cpp, oled_shim.cpp]
2026-09-06 Fix a dangling statement that flushed the display every loop pass
    ⚠ MY BUG, introduced in the previous commit by careless string patching:
    else if(inc != 0 && g_in_menu)
    menu_event((int)inc, false);
    g_oled_dirty = true; // NOT in the else-if
    Missing braces, so the dirty flag was set on EVERY iteration and the display
    flushed continuously -- worse than the 100 ms timer it was meant to replace.
    That is why the menu got MORE sluggish rather than less, and why main-menu items
    would not change: the loop was spending nearly all its time in I2C.
    Also moved encoder polling into the AUDIO CALLBACK, at a steady 750 Hz.
    The foreground loop runs at an irregular ~300 Hz -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
    [main.cpp]
2026-09-06 Splash meters, tuner fixes, backing level, and a shared-card note
    Splash is now settings + meters: preset, IR, engaged state, input and GR as
    BAR METERS with written values, and a clip indicator.
    ⚠ The IR row shows the preset's IR NAME even when it failed to load, marked '*'
    loaded / '!' not. Reporting a bare "none" for a preset that names an IR made a
    failed LOAD look like a preset with no IR -- two different faults that need
    telling apart, and the reason "tanglewood" looked IR-less.
    ⚠ Clip is STICKY until displayed rather than sampled. A single clipped sample
    between two 500 ms refreshes would otherwise never be seen -- and a transient is
    exactly what clips here.
    ⚠ TUNER: the buff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
    [main.cpp, menu.cpp, oled_shim.cpp]
2026-09-06 Fix IR path resolution and coalesce menu redraws
    ⚠ IR NEVER LOADED because the name was never resolved to a path. presets.txt
    names an IR as a bare filename ("tanglewood.wav") and the card keeps them in
    /tonetrix/ir/, but LoadIr() passed the bare name to the file opener, which
    looked in the ROOT. The preset was fine and the file was fine -- only the path
    was missing. An absolute name is now used as-is so a preset can still point
    anywhere on the card.
    The '!' marker added in the previous commit is what made this findable: it
    distinguished "preset names an IR that failed to load" from "preset has no IR",
    which had been reporting identically as "none".
    ⚠ Menu redraws are now event-driven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
    [main.cpp]
2026-09-06 Defer preset loading until the encoder settles
    ⚠ Turning the encoder at the HOME screen called SelectPreset() on every detent,
    which reads a WAV off the SD card and re-initialises the convolver -- hundreds
    of milliseconds each. Spinning through presets therefore appeared to hang for
    seconds, and forward-then-reverse was worst because it is two full loads.
    ⚠ It got noticeably WORSE right after the IR path fix, and that is the tell:
    before then the load failed fast, so its cost was invisible. Making a feature
    work exposed a cost that had always been there.
    Turning now moves an index and repaints immediately; the load fires once the
    encoder has been still for 400 ms. Spin freely and it co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
    [main.cpp]
2026-09-06 Fix silence with the DSP engaged: the convolver was called in-place
    ⚠ MY ERROR. TwoStageFFTConvolver::process(input, output, len) reads its input
    while writing its output, so passing the SAME buffer for both aliases them and
    the signal comes out silent. The Pico always used two buffers
    (s_dsp_in -> s_dsp_out); I collapsed that to one when wiring the callback.
    It only surfaced now because it needed an IR to actually load before the
    convolver ever ran -- g_ir_active was false until the path fix landed, so the
    faulty call was never reached. Second time today that fixing one thing exposed
    a latent bug behind it.
    Bypass was unaffected throughout, which is what localised it: dsp_chain_process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
    [main.cpp]
2026-09-06 Instrument the foreground loop instead of guessing at the menu stalls
    ⚠ Several rounds of theorising at "the menu is stuck" produced fixes that each
    helped a little and none of which settled it. This records the WORST case seen
    for oled_flush(), menu_render(), backing_service() and the whole loop iteration,
    so the next report says which one actually costs the time.
    Reported in the periodic summary line and by a new `times` command, which also
    resets the counters so a specific action can be measured in isolation.
    Ruled out on the way: backing_name() is a cached array lookup, not I/O, so the
    menu rows are not reading the card.
    Standing suspicion to test rather than assume: I2CHandle::Tran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
    [main.cpp]
2026-09-06 Apply every accumulated encoder detent, not just one
    ⚠ The instrumentation exonerated the foreground loop -- flush 24.1 ms (exactly
    the bit-count prediction, so the I2C is NOT stalling), render 197 us, service
    602 us, worst whole iteration 68.7 ms. Never seconds. That said the stall was
    not where I had been looking, and re-reading the code with that in mind found
    it:
    int32_t inc = g_enc_delta; // may be 3, 4, 5...
    g_enc_delta = 0;
    if(inc != 0)
    menu_event(inc > 0 ? 1 : -1, false); // collapsed to ONE step
    The callback banks every detent at 750 Hz but the foreground drains far less
    often -- a flush alone is 24 ms. Collapsing a batch of 3 into a single ste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
    [main.cpp]
2026-09-06 Measure the inter-iteration period, not just the work
    ⚠ The previous timing had a gap: it measured loop start to just BEFORE
    System::Delay(1), so anything happening in or between iterations was invisible.
    A reported 5-second hang should have shown loop ~5000000 and it showed 68738 --
    so either the hang did not occur during that capture, or it happens outside the
    instrumented work.
    g_t_period measures start-to-start, which cannot miss anything. If a hang shows
    in PERIOD but not in loop, the time is going somewhere the work timer does not
    cover and that narrows it decisively.
    Procedure for a clean capture: type `times` to reset, reproduce the hang, then
    `times` again -- the counters then d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
    [main.cpp]
2026-09-06 Make the timing wrap-safe: GetUs() wraps every ~21.5 seconds
    ⚠ REAL libDaisy GOTCHA, not just an instrumentation bug:
    uint32_t GetUs() { return GetTick() / (GetFreq() / 1000000); }
    GetTick() is a 32-bit hardware counter. Divided down to microseconds it wraps
    roughly every 21.5 SECONDS, and because it is a DIVIDED counter it does not wrap
    cleanly at 2^32 -- so ordinary unsigned delta arithmetic is wrong across a wrap.
    That is exactly the per=4273494460 reading: a 21.5 s jump backwards.
    The period timer now uses System::GetNow() (HAL_GetTick, clean milliseconds,
    wraps at 49.7 days). For hunting a multi-second stall, millisecond resolution is
    ample and correctness matters more than gra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
    [main.cpp]
2026-09-06 Send only changed display pages; the menu was latency, not hanging
    ⚠ The measurement settled what the guessing could not: max PERIOD 70 ms, w=0.
    There is NO multi-second hang in the foreground loop. The 5-second stalls seen
    earlier were the PRESET/IR LOADS -- visible in the same log at 55 s, 60 s and
    65 s -- not menu navigation.
    What remained was latency: a detent waited up to 50 ms for the rate limit and
    then 24 ms for the flush, so the screen trailed the knob by ~75 ms. That reads
    as "sticky" and no amount of redrawing less often would fix it.
    oled_flush() now compares each page against a SHADOW of what the panel actually
    holds and sends only the pages whose content changed. ⚠ The sh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
    [main.cpp, oled_shim.cpp]
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2026-09-06 Fix encoder: libDaisy's quadrature decode cannot decode a PEC11R
    Symptom: "turn one click slowly, nothing. Turn fast, nothing. Have to turn
    at a very specific rate." That is an ALIASING signature, not a load one --
    and it exonerates every display and timing fix of the last four rounds,
    because the counts were never being produced in the first place.
    libDaisy's Encoder::Debounce() (src/hid/encoder.cpp) emits a step on ONE
    exact sample pattern:
    A's last two samples == 0b10 AND B's last two samples == 0b00
    -- a falling edge on A at the instant B has already read low twice in a row.
    A PEC11R rests with both contacts OPEN (1,1) at every detent and runs
    1,1 -> 0,1 -> 0,0 -> 1,0 -> 1,1 thr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
    [main.cpp]
2026-09-06 Sample the encoder from a 10 kHz timer, not the audio callback
    The state-machine decode from the previous commit is correct -- the bench
    capture shows exactly one count per detent, correct direction, no
    over-counting. What remained was whole clicks producing NO line at all.
    That is a sample-rate problem, not a decode one. The audio callback runs at
    750 Hz (cb= confirms 3751 callbacks per 5 s), a 1.33 ms sample period, and a
    brisk flick takes a PEC11R through the whole 11 -> 01 -> 00 -> 10 -> 11 cycle
    in less than that. When every intermediate state falls between two samples
    the detent is invisible: nothing sampled, nothing to decode, no evidence.
    TIM4 at 10 kHz gives ~13 samples across tha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
    [main.cpp]
2026-09-06 Instrument the encoder PINS in the repeating line, add `encdet`
    Two decode fixes in a row each looked right on paper and each left detents
    missing -- and the last capture got WORSE (zero counts) while every printed
    line was still a clean +/-1, so the foreground is not batching them away.
    The counts are simply not being produced. Stop reasoning about the decode and
    measure the pins.
    The 5 s summary now carries:
    enc: tick= trans= cnt= raw= rest= sub= det= seen=
    separating three questions that have been running together:
    tick= did the sampler run, and at what rate (10 kHz => ~50000 per 5 s).
    This is the first hard evidence that TIM4 started at all -- the
    boot lin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
    [main.cpp]
2026-09-06 Add `encwatch` -- live A/B pin print, for hunting a dry encoder joint
    A cracked or dry leg on A or B fits the evidence better than any decode
    theory: mostly nothing, occasional CLEAN runs of +1/-1 in the right direction
    when the joint happens to make contact, and an apparent dependence on turn
    speed that is really dependence on how the knob loads the joint mechanically.
    A leg was broken during the build, so the suspicion has a cause.
    `encwatch on` prints A/B whenever the pins change, so the knob can be held
    still while each leg is wiggled: a connected leg toggles its pin, a dry one
    never moves. Rate-limited to 30 ms in the foreground -- at 10 kHz a bouncing
    contact would flood the console a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
    [main.cpp]
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2026-09-06 Full-screen tuner on the Daisy, matching the Pico's layout
    Tuning is a MODE, not a status line. When the tuner is armed it is the only
    thing wanted on the display, and the output is muted in that mode anyway so
    the flush costs nothing audible. Replaces the single "TUNE ..." strip that
    shared the home screen with the meters.
    ⚠ NO "listening" text and NO needle until a note is actually found. A word
    that appears and disappears draws the eye to the wrong place, and a needle
    parked at centre with no signal reads as "in tune" -- which is worse than
    reading as nothing. The empty scale is the honest idle state: it shows the
    instrument is armed and where the answer will appear, and claims nothing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
    [main.cpp, oled_shim.cpp]
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2026-09-06 Align the three home-screen meter bars to one column
    in and gr started their bars at x=18, out at x=24, so the three did not line
    up. ⚠ Bars that start at different x read as different SCALES -- which is the
    one thing a meter must not imply, since the whole point of stacking them is
    comparing down the column.
    All three now share kMeterX/kMeterW, so they cannot drift apart again when a
    label changes width. x=24 clears the widest label ("out", 3 chars = 18 px)
    with a space; the written values still start at 84.
    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
    [main.cpp]
2026-09-06 Fix the wrap-unsafe microsecond clock; SERVICE_BUDGET_US verified OK
    The bench capture showed "max service=4273495447 us" -- a 4273-second read.
    System::GetUs() is GetTick() DIVIDED DOWN, so its value rolls over at ~21.47e6
    rather than at 2^32, and ordinary unsigned delta arithmetic across that
    rollover is simply wrong.
    ⚠ That was not cosmetic. backing_service() bounds its work with
    `(time_us_32() - t0) < SERVICE_BUDGET_US`, and across a rollover the
    comparison goes true immediately -- so once every 21.5 s the service returned
    having done nothing and the backing track was starved for no reason.
    tt_shim_now_us() now accumulates RAW tick deltas into a 64-bit counter. Tick
    deltas are wrap-s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
    [main.cpp, sd_daisy_shim.cpp]
2026-09-06 Complete the `help` list, reset the CPU peak in `times`, add a menu timeout
    HELP was missing eight commands that exist: times, enc, enc on|off,
    encwatch on|off, encdet 2|4, bk stat, bk bench -- and `help` itself. ⚠ A
    diagnostic nobody can find is a diagnostic that does not exist, and this list
    is the only place they are discoverable: the boot report is routinely lost to
    CDC enumeration. Now grouped (general / presets+audio / backing / encoder).
    `times` now prints the CPU figures and RESETS THE PEAK along with the rest.
    A peak held since boot answers "what was the worst ever", which is not the
    question when testing a change -- and it never comes back down to say the
    change helped. Now it c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
    [main.cpp]
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
